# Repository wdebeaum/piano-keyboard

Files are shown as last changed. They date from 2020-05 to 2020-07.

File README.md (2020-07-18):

# Modular Piano Keyboard

By William de Beaumont

[CC BY 4.0](https://creativecommons.org/licenses/by/4.0/)

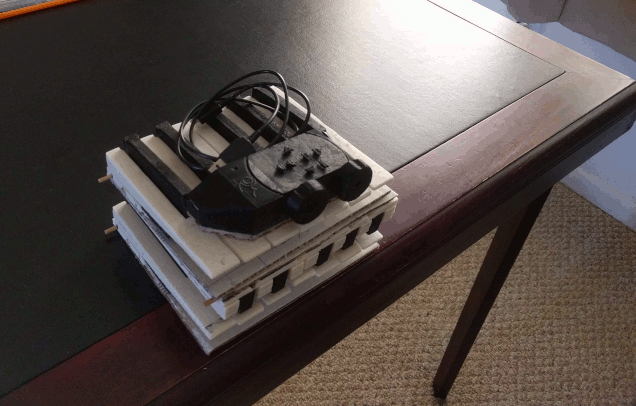
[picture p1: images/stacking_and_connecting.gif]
three octaves and end piece being unstacked and then connected


## Description

A DIY portable electronic piano keyboard with full-size keys, composed of several identical single-octave modules plugged together. Made using 3D printing, through-hole soldering, and easily obtainable parts.

Each key has two switches that close at different heights, in order to detect the velocity with which the key is pressed. Each octave (12 keys) has 3 8-bit shift registers that take input from the 24 switches in parallel, and shift output out serially, down towards the low (left) side of the keyboard.

That side may be connected to an end piece that uses a Teensy 4.0 to drive the shift registers and act as a USB MIDI controller. The end piece also has pitch bend and modulation wheels, a connection for a sustain pedal, and buttons to adjust a few settings.

Alternatively, you can connect that side of the keyboard to your own microcontroller, using an SPI port and one GPIO pin. The included `spi2midi` program will turn keypresses into MIDI commands on `stdout` if it is run on a Raspberry Pi connected to the keyboard as shown in [`wiring.h`](wiring.h).

## Instructions

 - [Bill of Materials](BOM.md)

 - [Building Instructions](BUILD.md) (many pictures)

 - [Usage Instructions](USAGE.md)

## Known issues

 - The key switches sometimes get out of alignment, preventing specific keys from triggering consistently until you take the key off and realign the switch.

 - The connection between the lowest octave and the end piece is a bit wobbly with only one alignment pin.

 - The pitch bend knob has no centering mechanism. I tried to make various kinds of springs for it, but the results were unsatisfying.

 - The hole in the end piece enclosure intended to let the LED on the Teensy shine through is too far away from it to matter. Maybe a light pipe would improve it. But as it is, the light shines out the right side anyway, so whatever.

## Future work

 - Better integration with ALSA MIDI ports on RasPi, ultimately letting it act as a standalone musical instrument by connecting to a soft synth.

 - Surface-mount version of octave PCB for mass production? Switches are still labor-intensive, though.

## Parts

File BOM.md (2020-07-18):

# Modular Piano Keyboard

## Octave Bill of Materials

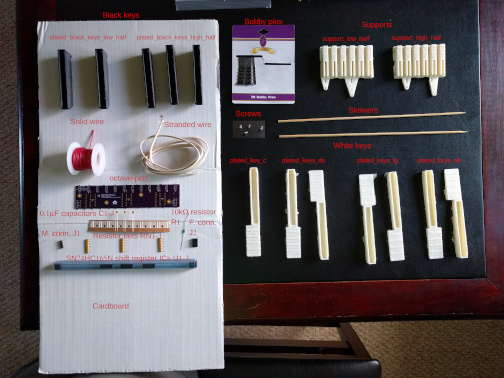
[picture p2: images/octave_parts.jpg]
picture of the parts listed below, laid out on a table


Quantities shown here are for one octave (though you probably want to make at least 3).

### Printed plastic parts

| Ref. | Qty | Description |
|:---- | ---:|:---- |
| `support` | 1 | support for whole octave (or two halves below) |
| `support_low_half` | 1 | support for C-F keys |
| `support_high_half` | 1 | support for F♯-B keys |
| `black_key` | 4 | regular black keys |
| `key_a_sharp` | 1 | A♯ key |
| `key_c` | 1 | C key |
| `key_d` | 1 | D key |
| `key_e` | 1 | E key |
| `key_f` | 1 | F key |
| `key_g` | 1 | G key |
| `key_a` | 1 | A key |
| `key_b` | 1 | B key |

These total about 40cm<sup>3</sup> of black plastic, 60cm<sup>3</sup> of white plastic, and 50cm<sup>3</sup> of additional plastic of any color (the color of the supports doesn't matter).

### Electronic components

| Ref. | Qty | Mfg. part no. | Digikey part no. | Description |
|:---- | ---:|:--- |:--- |:--- |
| U1-3 | 3 | SN74HC165N | 296-8251-5-ND | 8-bit PISO shift register |
| C1-3 | 3 | K104Z15Y5VF5TL2 | BC1160CD-ND | 0.1μF capacitor |
| RN1-3 | 3 | 4609X-101-103LF | 4609X-101-103LF-ND | 8×10kΩ bussed resistor array |
| R1 | 1 | RNF14FTD10K0 | RNF14FTD10K0CT-ND | 10kΩ resistor |
| J1 | 1 | PPTC051LGBN-RC | S5441-ND | 5-pin horiz. 0.1" pitch header, male |
| J2 | 1 | PRPC005SBAN-M71RC | S1111EC-05-ND | 5-pin horiz. 0.1" pitch header, female |

Note that many of these parts are shared between the octaves and the end piece, so you might want to take that into account when computing quantities to order. Even if you don't want to use the Teensy-based end piece, you might want to order 3 more resistors for the whole keyboard, so you can make the level shifter/voltage divider for connecting the 5V output of the keyboard to a 3.3V input on a Raspberry Pi or other microcontroller, as shown in `wiring.h`.

### Other parts and materials

| Qty | Description | How to get |
| ---:|:---|:--- |
| 12 | Bobby pin (metal) | Grocery store, hair care section, pack of 50, UPC 8 50899 00111 0 |
| 4 | M3 machine screw (length ~6mm) | Electronics/hardware store |
| 2 | Bamboo skewer (diameter 3mm, length >= 162.5mm) | Grocery store, barbecue section? pack of... many |
| 1 | Printed circuit board | OSH Park |
| ~30cm | Stranded copper wire | Cut from old telephone cord |
| ~60cm | 22 AWG solid copper wire | I got mine from Adafruit |
| 162.5×138.8mm | Corrugated cardboard | Cut from shipping boxes |
| 141 joints' worth | Solder | been using the same spool forever... |
| ~6 | Cotton swab | Grocery store, probably near the acetone |
| enough to soak the swabs | Acetone | Grocery store, nail care section ("nail polish remover") |
| ~16 drops | Superglue | Grocery store, housewares section |

## End Bill of Materials

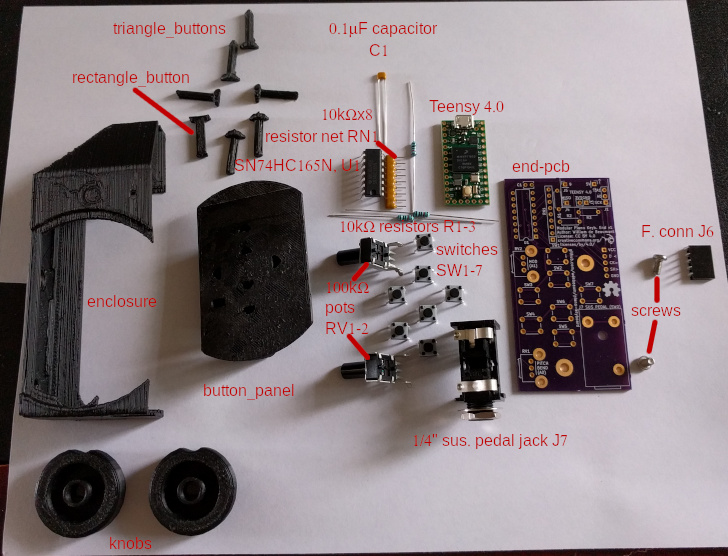
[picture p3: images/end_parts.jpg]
picture of most of the parts listed below, laid out on a table


Parts and quantities for one Teensy-based end piece. (Ignore R1-3 in the photo above, they were used in an earlier version.)

### Printed plastic parts

| Ref. | Qty | Description |
|:---- | ---:|:---- |
| `enclosure` | 1 | main body of enclosure |
| `button_panel` | 1 | part of enclosure around buttons |
| `triangle_button` | 6 | button shafts for directional buttons |
| `rectangle_button` | 1 | button shaft for clear button |
| `knob` | 2 | pitch bend/modulation knobs |

These total about 30cm<sup>3</sup> of plastic.

### Electronic components

| Ref. | Qty | Mfg. part no. | Digikey part no. | Description |
|:---- | ---:|:--- |:--- |:--- |
| J1-5 | 1 | DEV-15583 | 1568-DEV-15583-ND | Teensy 4.0 MCU board |
| U1 | 1 | SN74HC165N | 296-8251-5-ND | 8-bit PISO shift register |
| C1 | 1 | K104Z15Y5VF5TL2 | BC1160CD-ND | 0.1μF capacitor |
| RN1 | 1 | 4609X-101-103LF | 4609X-101-103LF-ND | 8×10kΩ bussed resistor array |
| RV1-2 | 2 | 09VR1M20F1N103B1 | CT3181-ND | 100kΩ potentiometer |
| SW1-7 | 7 | 1825910-6 | 450-1650-ND | SPST tactile pushbutton |
| J6 | 1 | PPTC051LGBN-RC | S5441-ND | 5-pin horiz. 0.1" pitch header, female |
| J7 | 1 | RA49B11 | SC2546-ND | 1/4" mono jack |

### Other parts and materials

| Qty | Description | How to get |
| ---:|:---|:--- |
| 2 | M3 machine screw (length ~6mm) | Electronics/hardware store |
| 1 | Bamboo skewer (diameter 3mm, length >= 30.5mm) | Grocery store, barbecue section? pack of... many |
| 1 | Printed circuit board | OSH Park |
| 42.4×109.3mm | Corrugated cardboard | Cut from shipping boxes |
| 87 joints' worth | Solder | been using the same spool forever... |
| ~5 drops | Superglue | Grocery store, housewares section |

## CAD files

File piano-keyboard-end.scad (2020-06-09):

/* piano-keyboard-end.scad - controls at the left end of piano-keyboard.scad
 * William de Beaumont
 * 2020-06-08
 */

/* TODO:
 - print most of enclosure on its left side
 - print part around buttons and screws separately, upside down
  - extend it all the way down towards the buttons and screw holes
  - make a lip around its edge so it holds down the rest of the top
 - recess the corresponding lip in the rest of the top so the two parts of the top are flush
  - must take care to leave room for sus pedal jack
 - print button extensions horizontally, with triangular cross-section to prevent rotation
  - make user ends of arrow buttons triangular too, pointing out from the center
  - make clear button end rectangular
 - extend holes for sus pedal jack and USB receptacle out towards the right to enable assembly
 - add upside-down shelves along PCB edges
 ? add ribs around inside top corners
 - remove most of bottom side (esp. around screw holes); use glued-on cardboard instead
 ? add skewer hole corresponding to the front one on octave (will it fit under teensy?)
 - taper top and left sides towards back, where teensy is
  - left side taper must be 45° to be printable
 - pitch bend knob torsion spring
  - two slots in knob opposite finger notch, to loop wire through
  - wire wraps around center post at least once
  - wire makes 90° bend to right on other side of knob, so knob can push wire into enclosure
  - two holes in left side of enclosure, near top, to poke other ends of wire through
*/

//
// printer-dependent parameters (see also piano-keyboard.scad)
//

wall_thickness = 1;
gap = 0.3;
thin_wall_deduction = 0.2;
sliding_deduction = 0.3;
epsilon = 0.01;
$fn=24;

//
// locations and sizes of PCB features
//

// reference point is top left corner of PCB; Y is inverted from KiCAD
// x->width, y->height, z->thickness

// the board itself
pcb_width = 1.62*25.4;
pcb_height = 3.23*25.4;
pcb_thickness = 1.6;

// Teensy 4.0
teensy_min_x = 0.87*25.4;
teensy_min_y = -0.35*25.4;
teensy_min_z = 0.1*25.4; // ???
teensy_width = 0.7*25.4;
teensy_height = 1.4*25.4;
teensy_thickness = pcb_thickness; // ???
// guessing based on pictures
teensy_led_x = teensy_min_x + 0.5*25.4;
teensy_led_y = teensy_min_y + 0.13*25.4;
teensy_led_radius = 0.1*25.4/2;

// USB receptacle on Teensy 4.0
// (mostly guesswork from generic USB diagram I googled)
usb_width = 7.5;
usb_height = 2.75+3.35;
usb_thickness = 2.5;
// guessing it's centered on Teensy
usb_min_x = teensy_min_x + (teensy_width - usb_width)/2;
usb_max_y = teensy_min_y + teensy_height + 1.3;
usb_min_z = teensy_min_z + teensy_thickness;

// connector to keys
j5_x = pcb_width;
j5_min_y = -1.62*25.4;
j5_height = 0.5*25.4;
j5_thickness = 0.1*25.4;
j5_min_z = -(pcb_thickness+j5_thickness);

// screws
screw1_x = 1.12*25.4;
screw1_y = -1.35*25.4;
screw2_x = 0.67*25.4;
screw2_y = -2.9*25.4;

// buttons
button_radius = 3.51/2;
button_thickness = 5;
// button centers:
//    x1  x2  x3
// y1     sw1
// y2     sw2
// y3 sw3     sw7
// y4     sw6
// y5 sw4
// y6     sw5
button_x1 = 0.24*25.4;
button_x2 = 0.7*25.4;
button_x3 = 1.15*25.4;
button_y1 = -1.24*25.4;
button_y2 = -1.59*25.4;
button_y3 = -1.84*25.4;
button_y4 = -2.1*25.4;
button_y5 = -2.28*25.4;
button_y6 = -2.47*25.4;

// potentiometers
pot_shaft_radius = 6/2;
pot_shaft_max_x = 0.005*25.4;
pot_shaft_length = 20-8; // quoted as 8mm, but that includes pot body
pot_shaft_min_x = pot_shaft_max_x - pot_shaft_length;
pot_flat_length = 7;
pot_flat_depth = 6-4.5; // how far in from where the circumference would be otherwise
pot1_shaft_y = -1.35*25.4;
pot2_shaft_y = -2.9*25.4;
pot_shaft_z = 0.394*25.4;

// sustain pedal jack
sus_radius = 0.1875*25.4;
sus_x = 1.2730*25.4;
sus_y = -pcb_height;
sus_z = 0.492*25.4;

// max height above pcb of any component (sustain pedal jack)
top_component_thickness = 0.708*25.4;
// ditto for components on bottom (J5)
bottom_component_thickness = 0.1*25.4;

//
// other parameters
//

knob_radius = 15;
knob_width = pot_shaft_length - (wall_thickness+2*(gap+sliding_deduction));
knob_min_x = pot_shaft_min_x;
// use thicker outer wall for knobs so that the gap doesn't show much
knob_wall_thickness = 5;
finger_radius = 5;
finger_depth = 2;

//
// non-printed parts
//

module pcb() {
    translate([0,0,-pcb_thickness/2])
  import("piano-keyboard-end-pcb/piano-keyboard-end-pcb.stl");
  // teensy
    translate([teensy_min_x, teensy_min_y, teensy_min_z])
  cube([teensy_width, teensy_height, teensy_thickness]);
  // usb
    translate([usb_min_x, usb_max_y - usb_height, usb_min_z])
  cube([usb_width, usb_height, usb_thickness]);
}

//
// basic enclosure sketch
//

module enclosure_sketch() {
  difference() {
    electronics_height = pcb_height + teensy_height + teensy_min_y;
    electronics_thickness = top_component_thickness + pcb_thickness + bottom_component_thickness;
    electronics_min_z = -(pcb_thickness + bottom_component_thickness);
    // main body
      translate([-(gap+wall_thickness), -(pcb_height+gap+wall_thickness), electronics_min_z-(gap+wall_thickness)])
    cube([pcb_width+gap+wall_thickness, electronics_height+2*(gap+wall_thickness), electronics_thickness+2*(gap+wall_thickness)]);
    // main hollow
      translate([-gap, -(pcb_height+gap), electronics_min_z-gap])
    cube([pcb_width+gap+epsilon, electronics_height+2*gap, electronics_thickness+2*gap]);
    hole_thickness = wall_thickness+2*epsilon;
    // hole for usb receptacle
      translate([usb_min_x-gap, usb_max_y-hole_thickness+epsilon, usb_min_z-gap])
    cube([usb_width+2*gap, hole_thickness, usb_thickness+2*gap]);
    // hole for led (light pipe?)
      translate([teensy_led_x, teensy_led_y, top_component_thickness+gap-epsilon])
    cylinder(r=teensy_led_radius, h=hole_thickness);
    // hole for sustain pedal jack
      translate([sus_x, sus_y-gap+epsilon, sus_z])
      rotate([90,0,0])
    cylinder(r=sus_radius+gap, h=hole_thickness);
    // holes for pots
      translate([epsilon-gap, pot1_shaft_y, pot_shaft_z])
      rotate([0,-90,0])
    cylinder(r=pot_shaft_radius+gap+sliding_deduction, h=hole_thickness);
      translate([epsilon-gap, pot2_shaft_y, pot_shaft_z])
      rotate([0,-90,0])
    cylinder(r=pot_shaft_radius+gap+sliding_deduction, h=hole_thickness);
    // holes for button stalks
      translate([0, 0, top_component_thickness+gap-epsilon])
    union() {
	translate([button_x2, button_y1, 0])
      cylinder(r=button_radius, h=hole_thickness);
	translate([button_x2, button_y2, 0])
      cylinder(r=button_radius, h=hole_thickness);
	translate([button_x1, button_y3, 0])
      cylinder(r=button_radius, h=hole_thickness);
	translate([button_x3, button_y3, 0])
      cylinder(r=button_radius, h=hole_thickness);
	translate([button_x2, button_y4, 0])
      cylinder(r=button_radius, h=hole_thickness);
	translate([button_x1, button_y5, 0])
      cylinder(r=button_radius, h=hole_thickness);
	translate([button_x2, button_y6, 0])
      cylinder(r=button_radius, h=hole_thickness);
    }
  }
}

//
// mod/pitch pot knob
//

module knob() {
  difference() {
    union() {
      // outer body
      difference() {
	cylinder(r=knob_radius, h=knob_width);
	  translate([0,0,wall_thickness])
	cylinder(r=knob_radius-knob_wall_thickness, h=knob_width-wall_thickness+epsilon);
	// finger notch
	  translate([-(knob_radius+finger_radius-finger_depth), 0, -epsilon])
	cylinder(r=finger_radius, h=knob_width+2*epsilon);
	// TODO anchor for torson spring for pitch bend knob
      }
      // inner post
      cylinder(r=pot_shaft_radius+gap+wall_thickness, h=knob_width);
    }
    // shaft hole
      translate([0,0,-epsilon])
    difference() {
      cylinder(r=pot_shaft_radius+gap, h=knob_width+2*epsilon);
      // flat
	rotate([0,0,-90])
        translate([
	  -(pot_shaft_radius+gap+epsilon),
	  pot_shaft_radius+gap-pot_flat_depth,
	  -2*epsilon
	])
      cube([
        2*(pot_shaft_radius+gap+epsilon),
        2*(pot_shaft_radius+gap+epsilon),
        pot_flat_length - gap + 2*epsilon
      ]);
    }
  }
}

%pcb();
enclosure_sketch();
  translate([pot_shaft_min_x, pot1_shaft_y, pot_shaft_z])
  rotate([0,90,0])
knob();
  translate([pot_shaft_min_x, pot2_shaft_y, pot_shaft_z])
  rotate([0,90,0])
knob();

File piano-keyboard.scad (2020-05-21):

/* piano-keyboard.scad - piano keyboard with dimensions copied from my midi keyboard
 * William de Beaumont
 * 2020-05-21
 */

//
// measurements
//

// measurements taken from my optimus md-1150
octave = 162.5;
white_width = 21.8;
white_gap = octave / 7 - white_width; // suspiciously close to sqrt(2)
black_width = 11; // but slightly narrower at the top
black_top_width = 9.8; // ?
white_depth = 134;
black_min_depth = 77; // at top
black_max_depth = 84; // at bottom, next to top of white key
white_travel = 16.9 - 6.1; // at max end of white key
// measured
//black_travel = 12 - 5.6; // ? at max end of black key (but tilted)
// calculated with the assumption that the travel angle is the same for b&w
black_travel = white_travel * black_max_depth / white_depth;
// height of black key above white key, with neither depressed
black_min_height = 8; // at min end of key, toward fulcrum
black_max_height = 12; // at max end of key
corner_radius = 1.5; // ? approx (maybe less for top of black keys)
// ^^^ doesn't apply to cutouts in white keys for black keys

// measurements from paper transfer
c_stem_width = 13;
d_stem_width = 14;
e_stem_width = 12.75;
f_stem_width = 12.1;
g_stem_width = 12.15;
a_stem_width = 12.15;
b_stem_width = 12.1;

black_gap =
  (octave - 
    ( // add up everything but the black gaps
      c_stem_width +
      d_stem_width +
      e_stem_width +
      f_stem_width +
      g_stem_width +
      a_stem_width +
      b_stem_width +
      5*black_width +
      2*white_gap
    )
  ) / 10;

c_x = 0;
c_sharp_x = c_x + c_stem_width + black_gap;
d_x = c_sharp_x + black_width + black_gap;
d_sharp_x = d_x + d_stem_width + black_gap;
e_x = d_sharp_x + black_width + black_gap;
f_x = e_x + e_stem_width + white_gap;
f_sharp_x = f_x + f_stem_width + black_gap;
g_x = f_sharp_x + black_width + black_gap;
g_sharp_x = g_x + g_stem_width + black_gap;
a_x = g_sharp_x + black_width + black_gap;
a_sharp_x = a_x + a_stem_width + black_gap;
b_x = a_sharp_x + black_width + black_gap;

// echo centers of key stems in inches for PCB layout
echo(
c=(c_x +c_sharp_x )/(2*25.4),
cs=(c_sharp_x +d_x )/(2*25.4),
d=(d_x +d_sharp_x )/(2*25.4),
ds=(d_sharp_x +e_x )/(2*25.4),
e=(e_x +f_x )/(2*25.4),
f=(f_x +f_sharp_x )/(2*25.4),
fs=(f_sharp_x +g_x )/(2*25.4),
g=(g_x +g_sharp_x )/(2*25.4),
gs=(g_sharp_x +a_x )/(2*25.4),
a=(a_x +a_sharp_x )/(2*25.4),
as=(a_sharp_x +b_x )/(2*25.4),
b=(b_x +octave)/(2*25.4)
);

/* bobby pin measurements
	o  ends
	|
	| o
max	|/	min length
length	|\
	|/  m
	|\
	| |
	| |
	 U

	 u
*/
bpin_width = 1.6;
bpin_thickness = 0.7;
bpin_end_thickness = 1.7; // max
bpin_u_radius = 5 / 2; // measured when unaltered: 3.8 / 2;
bpin_max_length = 50;
bpin_min_length = 46;
bpin_u_m = 17.5;
bpin_m_length = bpin_min_length - bpin_u_m;
bpin_m_pitch = 22 / 4;

bpin_angle = 7.4; // after unbending

// skewer measurements

skewer_radius = 3 / 2; // 3mm diameter skewers

// M3 screw measurements

/*   |    | head radius
      _________  ____
     /         \ head height
     |_________| ____
        <   >     ^
	<   >     threads height
	<___>    _V__
       |  | threads radius
*/

screw_threads_radius = 3/2;
screw_threads_height = 6;
screw_head_radius = 5/2;
screw_head_height = 2;

// electronics measurements

pcb_thickness = 1.6;
// this is what the TI datasheet says:
//chip_thickness = 2*2.54; // 2/10 inch
// this is what I measured (includes wide part of pins extending below plastic)
chip_thickness = (5/32) * 25.4; // 5/32 inch
// half of the 7/100 inch I shaved off the left side of the PCB to account for
// forgetting about the fact that the gap between keys is on the right side of
// the keys only when doing the above echo to get key stem centers in inches
pcb_x_fudge = - (7/2) * 0.254;

// mounting hole centers
//             inches
pcb_hole_1_x = 0.30	*25.4;
pcb_hole_1_y =-0.60	*25.4;
pcb_hole_2_x = 1.95	*25.4;
pcb_hole_2_y =-1.05	*25.4;
pcb_hole_3_x = 4.05	*25.4;
pcb_hole_3_y =-0.60	*25.4;
pcb_hole_4_x = 5.75	*25.4;
pcb_hole_4_y =-1.05	*25.4;

pcb_hole_radius = 3.2 / 2;

// 22 AWG wire
wire_radius = 0.644/2;

// end measurements

//
// parameters that depend on printer capabilities
//

// height of a single layer of extrusion
layer_height = 0.4;
// how thick should walls be, in general?
wall_thickness = 1;
// size of gap between parts that are meant to fit together but not slide easily
gap = 0.3;
// additional gap for thin walls that tend to ooze and become thicker than
// designed
thin_wall_deduction = 0.2;
// additional gap for parts that are meant to slide easily past each other
sliding_deduction = 0.3;
// how much small vertical holes shrink (additional radius to compensate)
small_v_hole_shrinkage = 0.25;

// small value used to avoid coinciding surfaces for CSG operations
epsilon = 0.01;

// use many facets for cylinders
$fn=24;

//
// common computed values
//

// gap between keys and their supports
support_gap = gap + thin_wall_deduction + sliding_deduction;

// thickness of top of white keys (relevant at thin end toward player)
white_thickness = 2*corner_radius;

// key hinge dimensions
hinge_radius = 2*wall_thickness;
hinge_height = wall_thickness + 0.5/*for imperfect printing*/;

// dimensions of extra chunk at back of each key, behind hinge
key_back_width = black_width;
key_back_depth = hinge_radius + wall_thickness + support_gap + wall_thickness;
white_back_height = white_travel + white_thickness;
black_back_height = white_back_height + black_min_height;

// dimensions of hollow underside of each key
hollow_width = key_back_width - 2*wall_thickness;
hollow_height = white_travel;

// dimensions of key supports and base
support_base_height = pcb_thickness + chip_thickness;
support_width = hollow_width - 2*support_gap;
support_depth = 50;
support_back_depth = 3*wall_thickness;

skewer_hole_radius = skewer_radius + gap + sliding_deduction;

support_hole_ir = screw_threads_radius + small_v_hole_shrinkage; // NOTE: no gap so threads bite
support_hole_or = support_hole_ir + wall_thickness;

//
// parts
//

// bobby pin (for showing assembly)
module bpin() {
    translate([0,-(bpin_min_length - bpin_u_radius),-bpin_u_radius])
  cube([bpin_width, bpin_min_length - bpin_u_radius, bpin_thickness]);
    rotate([-bpin_angle,0,0])
    translate([0,-(bpin_max_length - bpin_u_radius),bpin_u_radius - bpin_thickness])
  cube([bpin_width, bpin_max_length - bpin_u_radius, bpin_thickness]);
    rotate([0,90,0])
  cylinder(r = bpin_u_radius, h = bpin_width);
}

// hole in support for bobby pin
module bpin_hole() {
  intersection() {
    // NOTE: could have used bpin_max_length instead of support_depth, but would have made disassembly hard
      translate([0, -support_depth, -(bpin_u_radius + support_gap)])
    cube([bpin_width + 2*support_gap, support_depth, black_back_height]);
      rotate([-bpin_angle,0,0])
      translate([-epsilon, -support_depth, bpin_u_radius+support_gap-black_back_height])
    cube([bpin_width + 2*support_gap + 2*epsilon, support_depth, black_back_height]);
  }
    rotate([0,90,0])
  cylinder(r = bpin_u_radius + support_gap, h = bpin_width + 2*support_gap);
}
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

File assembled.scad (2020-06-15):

include <octave.scad>;
include <end.scad>;

module assembled() {
  assembled_octave();
  /* too much for OpenSCAD to handle
    translate([octave,0,0])
  assembled_octave();*/
    translate([-(pcb_width+support_gap),-(support_depth - key_back_depth)+skewer_hole_radius+5*wall_thickness-skewer_y/*-support_gap*/,-support_gap])
  assembled_end();
}

// To view, comment out assembled_end() in end.scad and assembled_octave() in
// octave.scad, then uncomment the following:
//assembled();

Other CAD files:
common.scad
end.scad
logo.scad
octave.scad

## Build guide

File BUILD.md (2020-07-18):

# Modular Piano Keyboard

## Octave Building Instructions

These are the building instructions for a single octave module of the modular piano keyboard. The instructions for the end piece that connects the octaves to a computer appear later in this document.

### Plastic Parts

The keys and their support structure can be printed on a 3D printer. Open `octave.scad` in [OpenSCAD](https://www.openscad.org/). By default this shows one assembled octave, including ghosts for the non-printed parts. You can also see a version with a cutaway in the C key to show how things fit together, by commenting out `assembled_octave();` and uncommenting `cutaway();`, at the end of the file.

You may need to adjust some parameters in the section labeled "parameters that depend on printer capabilities". I use an original [Printrbot](https://reprap.org/wiki/Printrbot), printing in ABS plastic onto blue painter's tape with a coating of ABS glue (made by dissolving waste ABS in a small amount of acetone to make it just gooey enough to spread). The Printrbot has a relatively small print bed (~ 124mm × 144mm, the white keys just barely fit), and printing in ABS onto tape means I have to worry a lot about prints curling up due to differential thermal contraction, especially with long thin pieces like piano keys. I also tend to have problems with close-fitting parts, solved with the `gap` parameter and a few others for specific situations. These issues are why I don't include my STL files here, only the original OpenSCAD file; you really should make your own STLs.

To show printable parts, comment out `assembled_octave();` and uncomment one line at a time from the "recommended printing order" section (make sure to read the comments there for more tips). You can then generate an STL file for each print (`Design` > `Render`, then `File` > `Export` > `Export as STL...`). I use Slic3r to generate gcode from the STL, with 20% fill density, and 2 solid layers on all sides.

Note that you have a couple of options for printing the black keys and the supports. I use the separate low and high halves for both, but if your printer is big enough and you're not worried about curling, you can try printing a whole octave at a time.

White keys are printed two at a time, again for space and curling reasons, but also because fit issues are likely to show up here. You wouldn't want to print a whole octave of white keys only to find out they don't quite fit on the supports and you have to adjust the parameters slightly. If you do in fact want to print a whole octave of white keys, you can try calling `plated_white_keys();` instead. If you are having curling issues, I don't recommend trying to print the white keys one at a time diagonally; I tried that a couple of times and had bad results.

You should be checking that the keys fit on their supports immediately after printing them, so that you can either make adjustments to the parameters, or just shave or sand them down to make them slide freely up and down. See "Attach keys" below. You should also check that the bobby pins fit in each slot before soldering them to the PCB. You might want to assign specific pins to specific slots in order to fine tune how the pins are bent, so that the white keys sit at the same height and require the same force to press.

Be careful when testing the bobby pins in their slots. They can shoot out suddenly, so keep a finger on them to prevent that, if it would stick a pin in your eye.

### Printed Circuit Board (PCB)

The circuit is designed in [KiCAD](https://kicad-pcb.org/). You can open the project file `octave-pcb/piano-keyboard-pcb-v2.pro` in KiCAD and use it to export Gerber files if you need to. I used [OSH Park](https://oshpark.com/)'s 2-layer prototype service, which accepts `.kicad_pcb` files directly. I got 3 copies of this board, unpopulated, for $44.45 delivered (this was by far the most expensive part, except for my own labor).

#### Solder components to the bottom

All the components on the PCB are through-hole soldered. Everything except for the switches (i.e. wires) goes on the bottom. I recommend leaving the switches for last, and doing everything else in order from thinnest to thickest:

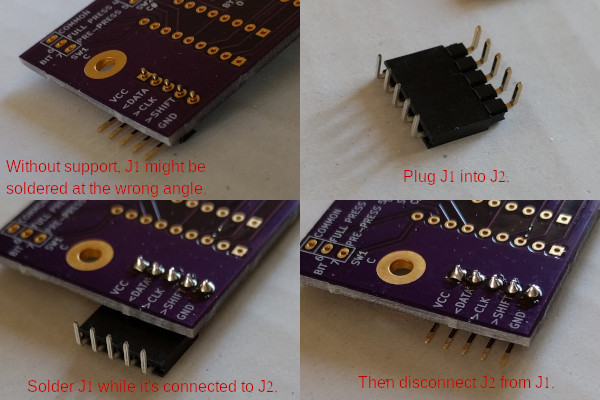
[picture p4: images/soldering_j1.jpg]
how to solder J1
 - Connectors J1-2. Do the male connector J1 first, while it's plugged into the female connector, to make sure there's enough space between the pins and the board.<br>
 - Resistor R1.
 - Chips U1-3. Note that these set the maximum height of the board.
 - Capacitors C1-3. These are about the same height; if not, bend them over a little.
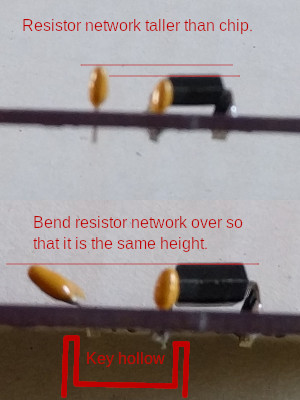
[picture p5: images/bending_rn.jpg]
how to bend RN1-3
 - Resistor networks RN1-3. These are slightly taller than the chips, but you can bend them over slightly before soldering. I recommend bending them away from the adjacent chips, so that the pins poking through the other side go towards the chips, and thus towards the middle of the key they're under. This should make them fit in the hollow in the bottom of the key when it's pressed.<br>

Cut off the excess leads from the resistor and capacitors, and optionally save them for later.

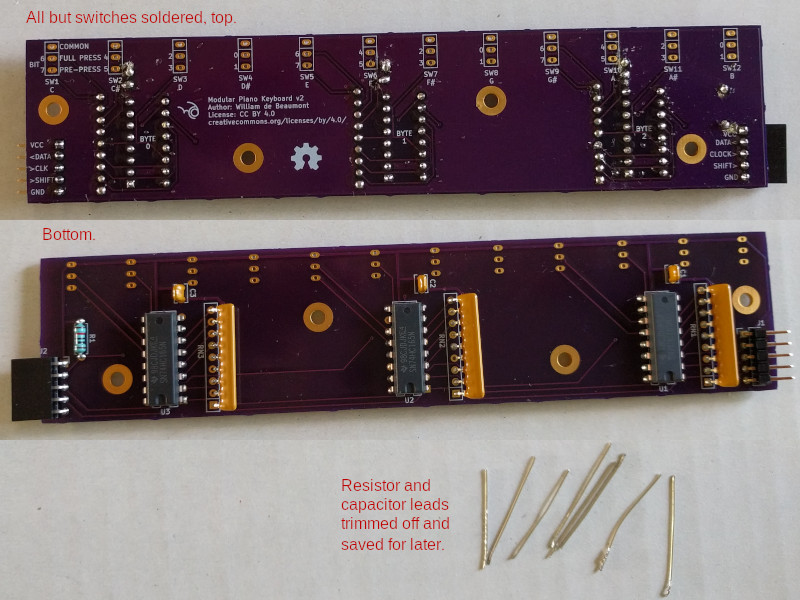
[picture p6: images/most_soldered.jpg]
board with most components soldered and leads trimmed


#### Make switches on the top

Make the switches from the bobby pins and wire, and solder them to the top side of the board (opposite all the other components):

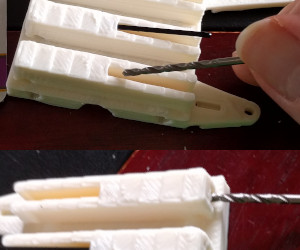
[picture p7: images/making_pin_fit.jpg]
making the pin fit
 - Unbend the bobby pin slightly, so that it fits snugly in the slots in the support, and takes an appropriate amount of force to push down. If it doesn't go in all the way, try reaming out the slot with a drill bit to remove any extra blobs of plastic that may be interfering (especially from the top, where the bridging might have sagged into the slot).<br>
 - Remove any coating from the wavy (bottom) side of the bobby pin where you'll be soldering, and from the inside of the straight (top) side where the other wires will make contact when the switch is closed. You can do this with acetone and a cotton swab. Don't remove the coating from the bulbs on the ends or they'll fall off and leave you with a sharp edge. Also don't inhale the acetone.
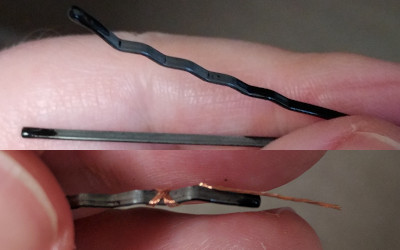
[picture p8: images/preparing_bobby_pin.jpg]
preparing the bobby pin
 - Cut 2-3cm of uninsulated stranded copper wire and wrap one end around the wavy side of the bobby pin, with enough of the end of the wire hanging over the end of the pin so that you can poke it through the hole closest to the edge of the PCB. Solder the wire and the pin together where you wrapped it.<br>
 - Solder that wire into that hole, making sure that the bottom side of the bobby pin ends right about where the PCB begins (no overlap, maybe a 1mm gap). If the wire is too short, the pin won't go all the way into its slot; if it's too long, it will arch up and interfere with the other wires.
 - Strip the ends of a ~2cm piece of solid copper wire, and solder it into the middle hole. You can reuse the leads cut off of the resistor and capacitors for some of these.
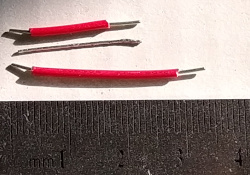
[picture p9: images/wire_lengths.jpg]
wire lengths
 - Similarly use ~3.5cm of solid copper wire with the last hole.<br>
 - Bend the shorter, middle wire straight into the middle of the bobby pin, with the free end bent up a little.
 - Bend the longer wire away from the bobby pin, along the board, and then make a sharp U-shaped bend up and back towards the middle of the bobby pin, not as far as the shorter wire. Again, bend the free end up, a little less than the shorter wire.

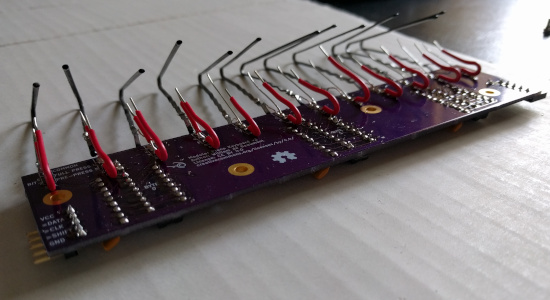
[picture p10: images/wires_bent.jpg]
bent wires


The wire bending doesn't have to be perfect for now; save that for when the PCB is inserted into the plastic support. The goal is for the bobby pin, when pressed down, to make contact with the long wire first, and then the short wire. The U-bend in the long wire makes it so it can spring back instead of being permanently bent down when you first press the key.

Note that the C and G keys have screw holes near where the longer wire is soldered. The U-bend in the longer wires for these keys should just about touch the screw heads. In general the U-bends for all the keys need to be tight in order to avoid having the key push down on the wire there and make it lose contact with the bobby pin.

After you're finished soldering, it's a good idea to check for short circuits with a multimeter. At least check that VCC and ground aren't shorted before plugging it in.

### Final Assembly

At this point, you should be sure that all the keys fit on their supports and slide freely. But leave the keys off for the next step.

#### Insert PCB into support

Line up all the bobby pins in their slots in the support, and start pushing them in. If you printed the support in two halves, you can do this one half at a time to make it easier. Be careful not to break the stranded wires connecting the pins to the PCB. You can use the top of one of the white keys as a tool to push on the top sides of all the pins at once, to make them go in evenly. Be patient. Note that if the switch wires stick out of the bottom side of the board a little, they might catch on the part of the support under the PCB. You can wiggle the PCB up and down a little to get past this, and get the wires that stick out into the depressions for them in the PCB support struts. Push the bobby pins and PCB all the way in, so the back edge of the PCB is up against the front of the main part of the support.

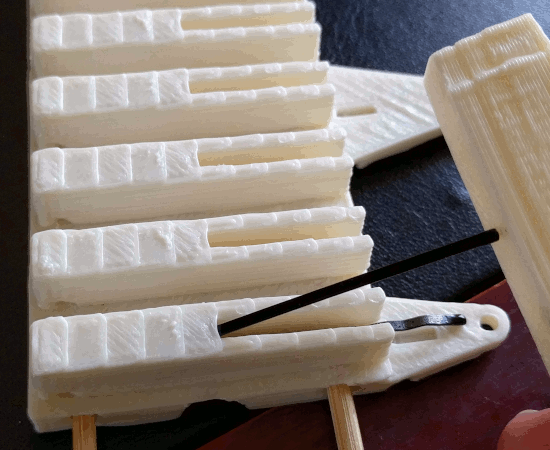
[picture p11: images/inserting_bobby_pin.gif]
inserting one pin

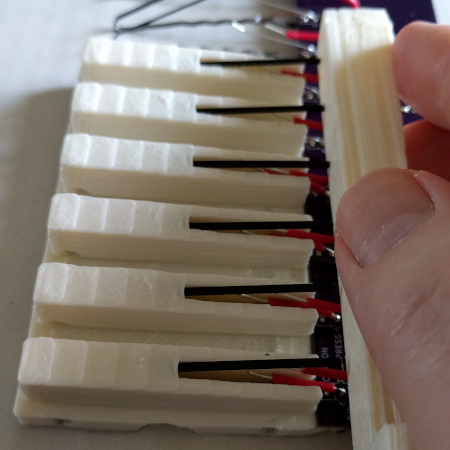
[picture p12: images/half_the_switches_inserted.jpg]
half the switches inserted


You should be able to see the back of the pins through the holes in the backs of the support walls. If you need to undo this step later you can poke another pin through those holes from the back, to loosen the pins.

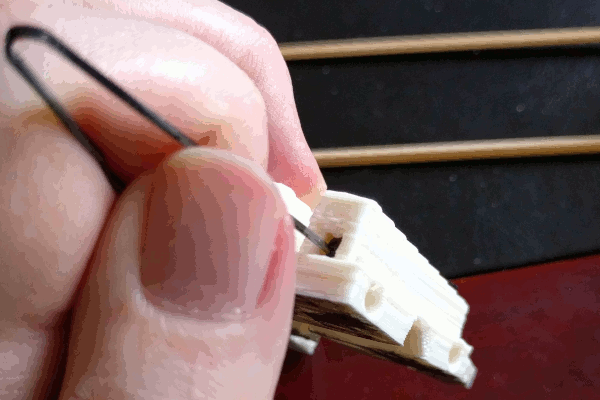
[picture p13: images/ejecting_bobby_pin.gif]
ejecting a pin from the back


#### Secure supports and PCB

Insert the skewers in the two horizontal holes in the bottom of the support (now is a good time, especially if you printed the support in two halves). You should cut them to the same length as the octave, 162.5mm. Insert them so that the back skewer hangs out of the left side by 1cm, and the front skewer hangs out of the right side by 1cm. If they're loose, you can glue them in place later. If they're too tight to insert, check for plastic blobs inside the holes getting in the way and remove them with a knife and/or a drill. If there's nothing in the way, try flexing the support to straighten the holes as you insert the skewers.

Insert the four screws through the PCB and into the corresponding holes in the support. You might need to use some force when screwing them in for the first time, in order to cut the threads into the plastic. Do this on a surface you don't care about the finish of, just in case the screws poke out a little from the bottom of the support.

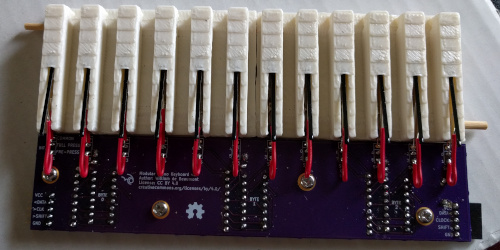
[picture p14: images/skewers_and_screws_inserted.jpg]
skewers and screws inserted


#### Check switches

Make sure the switch wires are bent properly (see PCB instructions above), since inserting the PCB into the support might have knocked them out of alignment. Look into the bobby pin slot from the front and press down on the top of the pin with your finger, so you can see if and when the wires make contact with the pin. You might also want to connect the electronics at this point so you can see when connections are being made that way. It will take some testing and iteration to get this right for each key. You can use an extra bobby pin or two as tools to help you adjust the positions of the wires while they are inside the support.

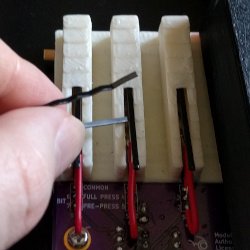
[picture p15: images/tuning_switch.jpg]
adjusting the switch wires for C♯ key with another bobby pin


#### Attach keys

Slide each key onto its support wall, and then slide it forward until the hinge snaps into place. Attach the white keys first and then the black keys. The white keys are C through B, left to right. The black keys are all the same except for the rightmost one, A♯, which has a notch on the bottom right side to accommodate one of the screw heads.

If you printed the support in two halves, check that the F key doesn't noisily rub against the F♯ and G keys. If it does, try to wiggle the support halves around until it doesn't. Failing that, shave down the keys where they rub.

#### Attach cardboard

Cut a rectangular piece of corrugated cardboard, 162.5mm × 138.8mm (these measurements are `echo`'d by OpenSCAD when you show the default `assembled_octave();` scene). Cut it so that the corrugations run parallel to the keys (along the Y dimension). This cardboard helps the keyboard not to tip forward when you play chords, so you don't want it to fold up along the X dimension.

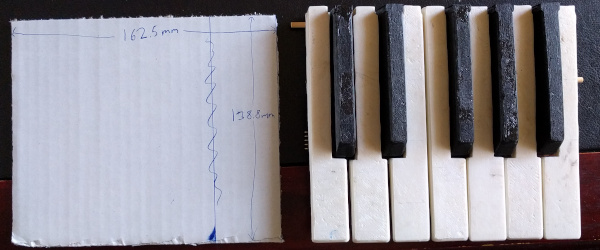
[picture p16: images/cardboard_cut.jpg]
cardboard cut to size


Turn the keyboard upside down and put a small amount of glue on each of the bottom surfaces (and on the skewers if they're still loose). Press the cardboard onto the glued surfaces, taking care to align the back corners of the support with the back corners of the cardboard. Turn the keyboard right side up again and let the glue set.

## End Building Instructions

These are the building instructions for the end piece that connects the chain of octaves to a computer as a USB MIDI device.

### Plastic Parts

The plastic parts of the end can be printed from `end.scad`. You will need the enclosure (`plated_enclosure()`), the button panel (`plated_button_panel()`), two knobs (`knob()`), six triangular buttons, and one rectangular button (`buttons_plated()`). I recommend printing the enclosure and button panel in white, and the knobs and buttons in black, for contrast. You can use the `white_plated()` and `black_plated()` modules to make this easy. But the colors aren't super important here; I was running out of white, so I used black plastic for everything.

You can also view the `assembled_end()` module to see how the end should look when assembled, or animate the `exploded_end()` module to see how to put it together.

You might need to drill out the screw holes in the conical posts on the bottom of the button panel in order to get the screws to fit, since the 3D printer might have dragged the plastic around, or oozed too much plastic, making the holes smaller. The design tries to account for this, but it's not an exact science.

### Firmware

Open `teensy-usb-midi/teensy-usb-midi.ino` in the Arduino IDE software with [Teensyduino](https://www.pjrc.com/teensy/td_download.html) installed. Make sure that in the `Tools` menu, the `Board` is set to `Teensy 4.0`, and `USB Type` is set to `MIDI`. Click the checkmark button in the top left to verify the sketch. This will compile the program and pop up the `Teensy` window. Then push the button on the Teensy with it connected to the computer, which will cause it to download the newly compiled program. (It's easier to reach the button now, before assembly.)

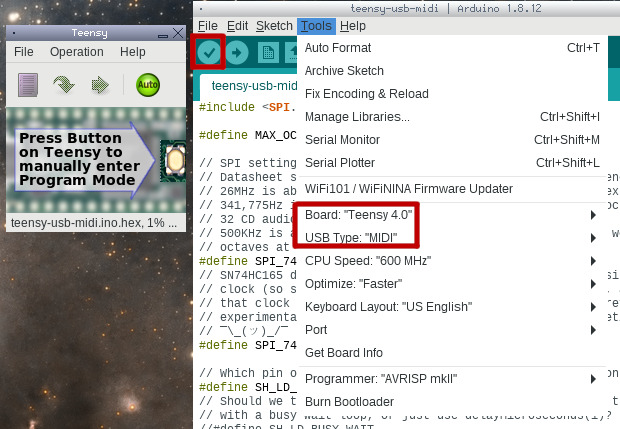
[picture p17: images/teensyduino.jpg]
teensyduino settings, compilation, and flashing


### Printed Circuit Board (PCB)

Again, this is designed in KiCAD (open `end-pcb/piano-keyboard-end-pcb.pro`) and ordered from OSH Park (this time for $26.20 for 3 boards, though I only needed one).

All components except for the 5-pin female connector (J6) belong on the top side of the PCB; J6 goes on the bottom, matching the octaves.

#### Solder shorter components to the top

Solder the resistor network RN1, the capacitor C1, and the chip U1 to the top of the board. Trim the leads from the capacitor, and save them so you can use them for the next step. (Ignore the individual resistors in the photos, they were only used in an earlier version.)

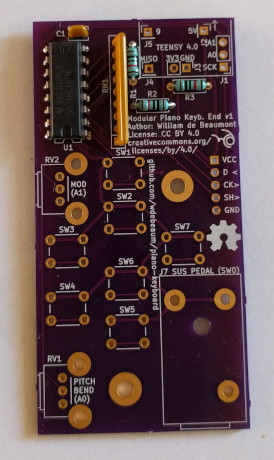
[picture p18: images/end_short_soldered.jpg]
shorter components soldered


#### Solder leads between Teensy and end PCB

Solder the saved leads and/or other solid wire to only the holes in the Teensy that have corresponding holes in the end PCB, in the area in the top right corner labeled `TEENSY 4.0`. All the leads should extend down from the bottom of the Teensy. (Ignore the red wire in the photos, it was only used in an earlier version.)

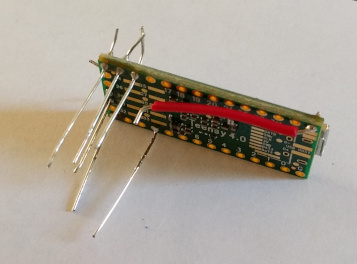
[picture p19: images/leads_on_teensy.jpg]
leads on Teensy


Insert the leads you just soldered to the Teensy into the corresponding holes in the end PCB. Then slide the two boards into the right side of the enclosure (see Final Assembly below) to get the spacing between the boards right. Solder two or three of the leads that are farther away from the plastic so you don't melt it. Then take the boards back out of the enclosure and finish soldering the rest of the leads.

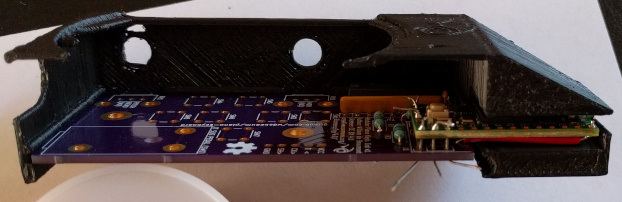
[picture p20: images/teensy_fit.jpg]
teensy fit in enclosure, on pcb


#### Solder taller components to the top

The rest of the top-side components will clip into place. Because of that, they don't need to be supported from below, so you can insert them all now and solder them in one pass: switches SW1-7, potentiometers RV1-2, and the sustain pedal jack J7. The potentiometers might be a little loose; if so, solder them in place before inserting J7, and be careful about keeping them angled correctly. However, if they end up a little off-kilter, you can shave the holes their shafts are supposed to go through in the enclosure until they fit and turn freely.

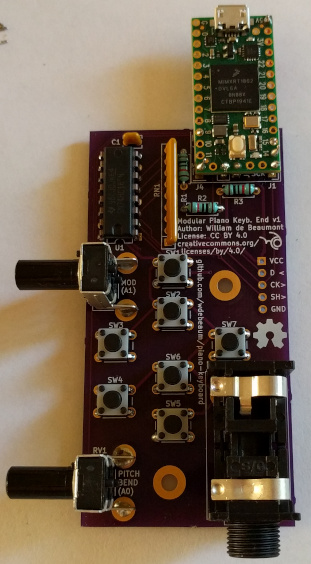
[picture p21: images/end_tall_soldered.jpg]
taller components soldered


#### Solder J6 to the bottom

Finally, solder the 5-pin female connector J6 to the bottom of the end PCB. The leads of the other components sticking out of the bottom will help support the PCB so that J6 is straight.

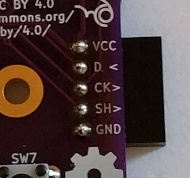
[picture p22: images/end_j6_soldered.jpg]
J6 soldered


### Final Assembly

Viewing the animated version of `exploded_end();` might be helpful here.

#### Insert PCB

Slide the end PCB into the enclosure from the right side, so that the edges go into their slots around the three other sides, the potentiometer shafts go through their holes on the left side, and the sustain pedal jack and the Teensy's USB port slide into their slots on the bottom and the top, respectively. You can thread the nut that came with the sustain pedal jack onto it from the outside, to secure it further.

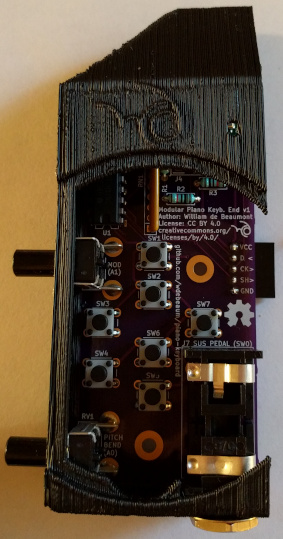
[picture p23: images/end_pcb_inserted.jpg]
end PCB inserted


#### Insert button panel and screws

Put the button panel into its hole in the top of the enclosure, so that the conical screw hole posts line up with the screw holes in the PCB, and screw in the two M3 screws from the bottom.

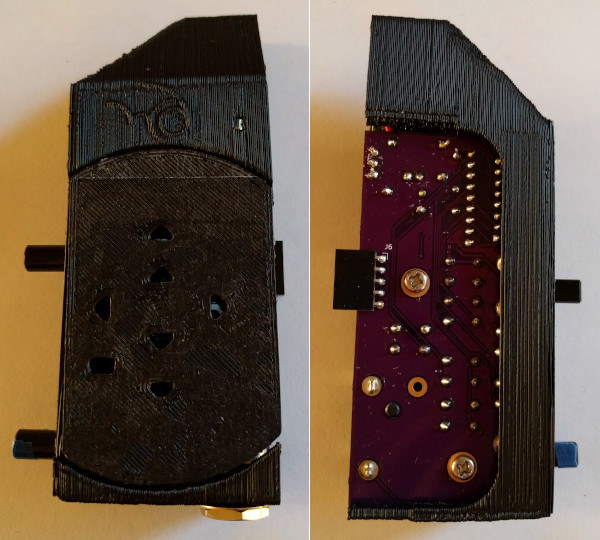
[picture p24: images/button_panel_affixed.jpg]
button panel affixed


#### Insert button shafts and add knobs

Put the button shafts into the button panel. They should feel tight most of the way, and then pop into place. After that, you should be able to feel the click of the switches on the PCB when you push the buttons.

Put the knobs onto the potentiometer shafts. If they're too loose to stay on, wrap a tiny bit of tape around the shafts to make the fit tighter.

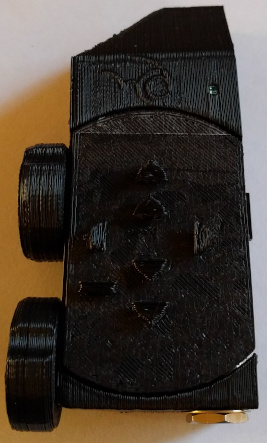
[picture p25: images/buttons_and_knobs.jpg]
buttons and knobs affixed


#### Test

This is a good time to test that everything works properly, since the gluing steps may make disassembly more difficult (in particular, the cardboard covers the screws and makes them inaccessible). See [USAGE](USAGE.md).

#### Glue skewer alignment pin

Cut and glue a 30.6mm piece of skewer into the groove just under the PCB where it connects to the Teensy. This should stick out of the right side by about 1cm, and it will go into the front skewer hole on the first octave when the keyboard is assembled.

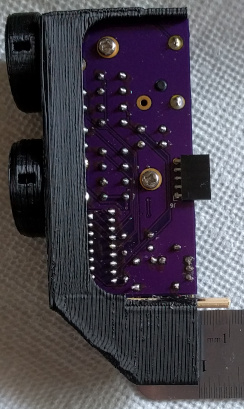
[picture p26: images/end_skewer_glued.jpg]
skewer glued


#### Glue cardboard base

Cut a 42.4×109.3mm piece of the same corrugated cardboard that you used for the bottoms of the octaves, with a 45° bevel cut off of the top left corner, 22.1mm in from the top and left edges. (These dimensions are `echo`'d by OpenSCAD when you show the default `assembled_end();` scene.) Glue it to the bottom of the end enclosure.

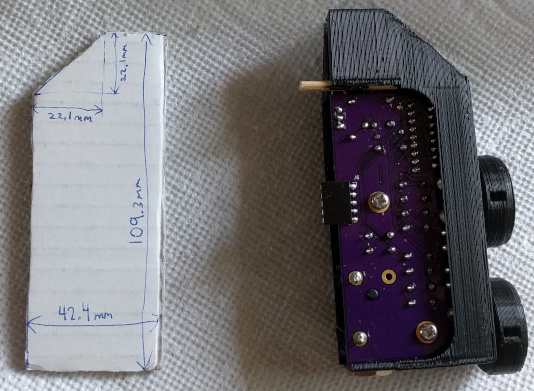
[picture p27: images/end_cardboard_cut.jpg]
cardboard cut


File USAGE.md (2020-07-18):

# Modular Piano Keyboard

## Usage Instructions

Build up to 10 octaves by repeating the [octave building instructions](BUILD.md). Connect them side to side on a flat surface, first lining up the skewers with their holes on the opposide side, and then pushing the octaves together so that the five-pin male connector on the right octave goes into the five-socket female connector on the left octave.

You have a number of options for connecting the octaves to something that will actually play notes:

### With a Teensy 4.0

Build the end piece using the [end building instructions](BUILD.md) (scroll down). Connect the left (five-pin male) connector on the lowest (leftmost) octave to the (five-pin female) connector on the right side of the end piece. Then connect the micro-USB connector on the back of the end piece to a computer or other device that understands USB MIDI devices. Optionally, connect a pedal switch to the 1/4" sustain pedal jack on the front of the end piece.

The front knob is a pitch bend knob. The back knob is for modulation. Not all MIDI synthesizers or instruments support these functions. When you first plug in the USB, the knobs are disabled; in order to enable them, you should calibrate them by moving them all the way in one direction, and then all the way in the other direction. For the best calibration you should have them in the center position (finger notch straight up) when the USB is connected.

The buttons allow you to adjust a few settings. The left and right buttons select which setting is being changed. The inner up and down buttons adjust the currently selected setting in fine increments, and the outer ones adjust it in coarse increments. The rectangular button in the bottom left resets the currently selected setting to the minimum possible value. There are currently 3 different settings you can change:

 1. Transposition. Fine adjustment is by semitone, coarse adjustment is by octave. On startup the lowest pitch on the keyboard is C5.
 2. Instrument (MIDI program). Fine adjustment is by instrument, coarse adjustment is by family (group of 8 instruments in the General MIDI instrument list). On startup this is the first instrument, Acoustic Grand Piano.
 3. MIDI channel. Fine adjustment moves by 1 channel at a time, coarse adjustment moves by 4 channels at a time. On startup this is the first channel.

When you push one of the buttons, the last note you played (or the lowest key if you haven't played any yet) is played again, with any changes applied: it is transposed, or on the new instrument, or on the new channel. This lets you know what you just did.

### With a Raspberry Pi

Connect the left connector on the lowest (leftmost) octave to a Raspberry Pi's 5V power (or 3.3V), SPI port, and one GPIO pin, as shown in the comments in `wiring.h`. If you connect to different pins, change the `#define`s in this file.

Copy this repo to the Pi, and run `make` there to compile the `spi2midi` program. If you run that program, it will write MIDI events to `stdout` for each keypress and release. It will also write debugging information to `stderr`, so it might be useful to do this to just see the debugging information while tuning the key switches:

    ./spi2midi >/dev/null

If, like me, you have a synthesizer connected to a MIDI port on your Linux computer, and you're accessing your Pi over ssh, you can route the MIDI events from the keyboard to the synthesizer with a command like this on your computer:

    ssh pi@pi path/to/spi2midi >/dev/snd/midiC0D0

### With another microcontroller

Connect the left connector on the lowest (leftmost) octave to a microcontroller with a 3.3V or 5V power source, an SPI port, and a GPIO pin. Back to front, the pins are:

 1. Vcc
 2. SPI MISO
 3. SPI clock (~350KHz-21MHz)
 4. Shift/load (connect to GPIO output pin; low loads switch state into the shift registers, high shifts state out of the registers)
 5. Ground

If you use a 5V power source, note that while the circuit will almost tolerate 3.3V inputs on pins 3 and 4 (most keys will work, but with 3 octaves the highest 3 keys won't work consistently), it will still output 5V on pin 2. If your microcontroller can't tolerate 5V on its SPI MISO pin, you should make a voltage divider to change it to something close to what it will tolerate. An easy way to do that is to arrange 3 extra 10kΩ resistors (the same kind you used for R1) like this:

                     SPI MISO on μcontroller (3.3V)
                                ^
                                |
    ground>---/\/\/\---/\/\/\---*---/\/\/\---<pin 2 of keyboard (5V)
               10kΩ     10kΩ         10kΩ

If you use 3.3V power and levels throughout, the voltage divider is unnecessary. And all the keys will work.

Your code should momentarily (min. 14-80ns depending on Vcc) drive pin 4 low, and then keep it high while reading from the SPI port. The first bit you receive will be the pre-press bit for the lowest key (nearest the controller) followed by the full press bit for the same key, followed by the same pattern for each higher key. The bits are labeled in a big-endian fashion within each byte on the PCB; full press bits are even, pre-press bits are odd.

You should read an octave at a time, and stop when you see an octave with all bits set (`0xffffff`); that's the pull-up resistor R1 in the highest octave, terminating the data line.

You should do a complete scan of the keyboard on the order of 1000 times a second. Note the time when the pre-press bit of a given key goes high, and then when you see the full press bit also go high (for two scans, to debounce), compute the time between the two transitions and use that as the velocity of the keypress. When you later see the full press bit go back to low, emit a key release.

Read `spi2midi.c` or `teensy-usb-midi/teensy-usb-midi.ino` for examples of how to do all this.

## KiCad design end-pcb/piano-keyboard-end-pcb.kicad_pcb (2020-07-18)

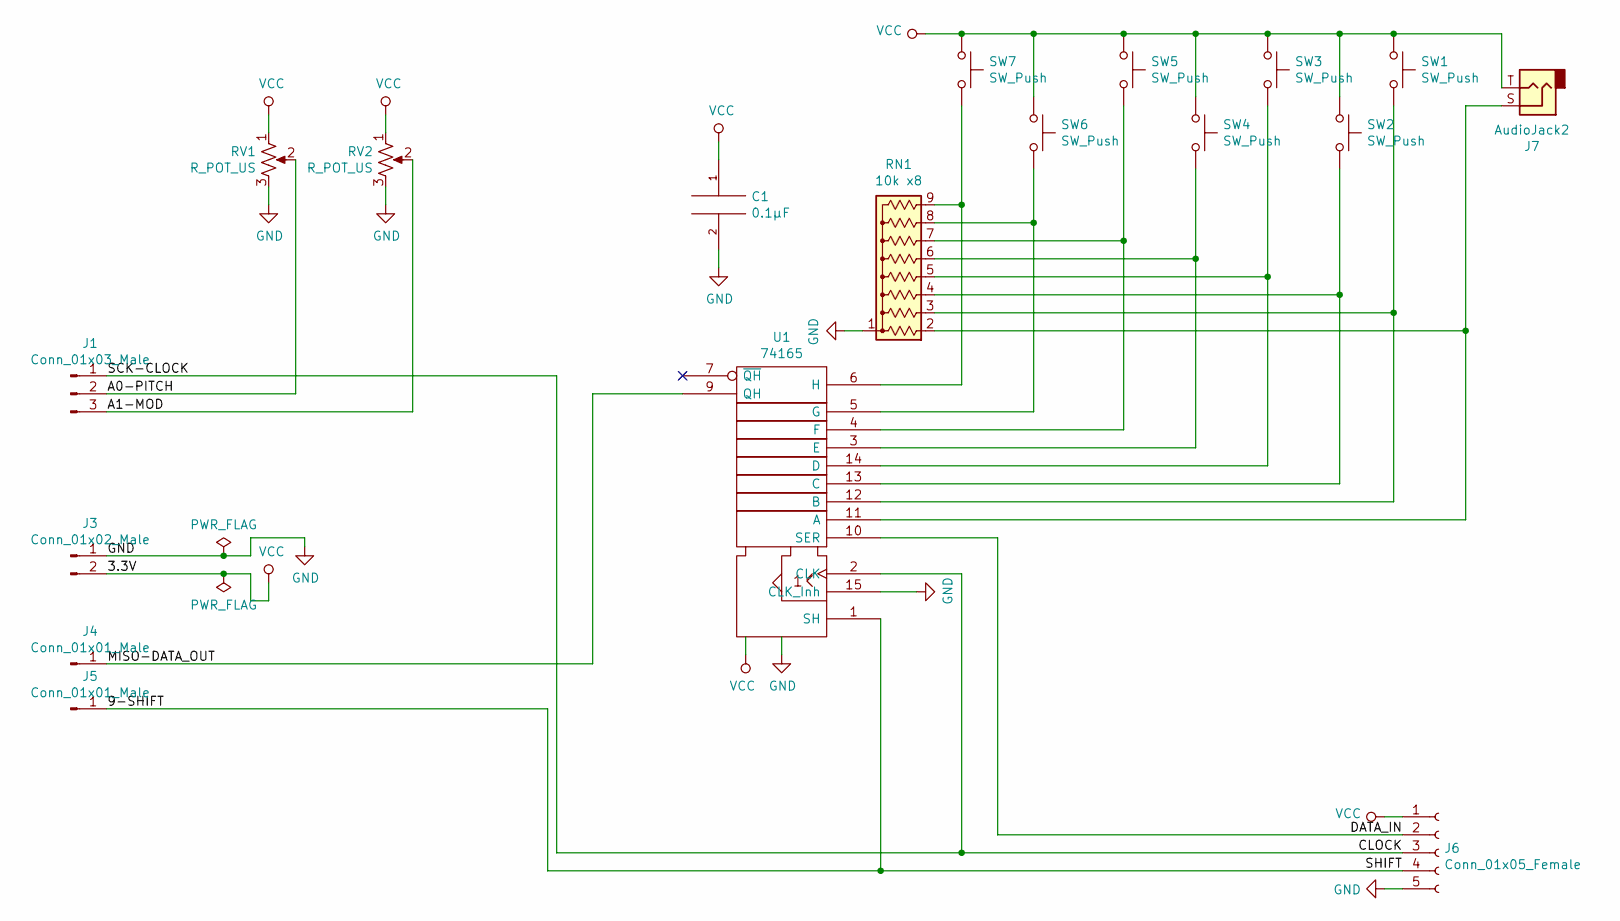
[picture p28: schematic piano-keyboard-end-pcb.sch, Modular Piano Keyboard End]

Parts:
C1: 0.1μF; C_Disc_D3.8mm_W2.6mm_P2.50mm
J1: Conn_01x03_Male; PinHeader_1x03_P2.54mm_Vertical
J3: Conn_01x02_Male; PinHeader_1x02_P2.54mm_Vertical
J4, J5: Conn_01x01_Male; PinHeader_1x01_P2.54mm_Vertical
J6: Conn_01x05_Female; PinSocket_1x05_P2.54mm_Horizontal
J7: AudioJack2; Switchcraft_RA49B11
RN1: 10k x8; R_Array_SIP9
RV1, RV2: R_POT_US; Potentiometer_Bourns_PTV09A-2_Single_Horizontal
SW1, SW2, SW3, SW4, SW5, SW6, SW7: SW_Push; SW_PUSH_6mm
U1: 74165; DIP-16_W7.62mm

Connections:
/9-SHIFT: J5.1, J6.4, U1.1 (SH)
/A0-PITCH: J1.2, RV1.2
/A1-MOD: J1.3, RV2.2
/CLOCK: J1.1, J6.3, U1.2 (CLK)
/DATA_IN: J6.2, U1.10 (SER)
/MISO-DATA_OUT: J4.1, U1.9 (QH)
GND: C1.2, J3.1, J6.5, RN1.1 (common), RV1.3, RV2.3, U1.8 (GND), U1.15 (CLK_Inh)
unnamed: J7.S, RN1.2 (R1), U1.11 (A)
unnamed: RN1.3 (R2), SW1.2, U1.12 (B)
unnamed: RN1.4 (R3), SW2.2, U1.13 (C)
unnamed: RN1.5 (R4), SW3.2, U1.14 (D)
unnamed: RN1.6 (R5), SW4.2, U1.3 (E)
unnamed: RN1.7 (R6), SW5.2, U1.4 (F)
unnamed: RN1.8 (R7), SW6.2, U1.5 (G)
unnamed: RN1.9 (R8), SW7.2, U1.6 (H)
VCC: C1.1, J3.2, J6.1, J7.T, RV1.1, RV2.1, SW1.1, SW2.1, SW3.1, SW4.1, SW5.1, SW6.1, SW7.1, U1.16 (VCC)

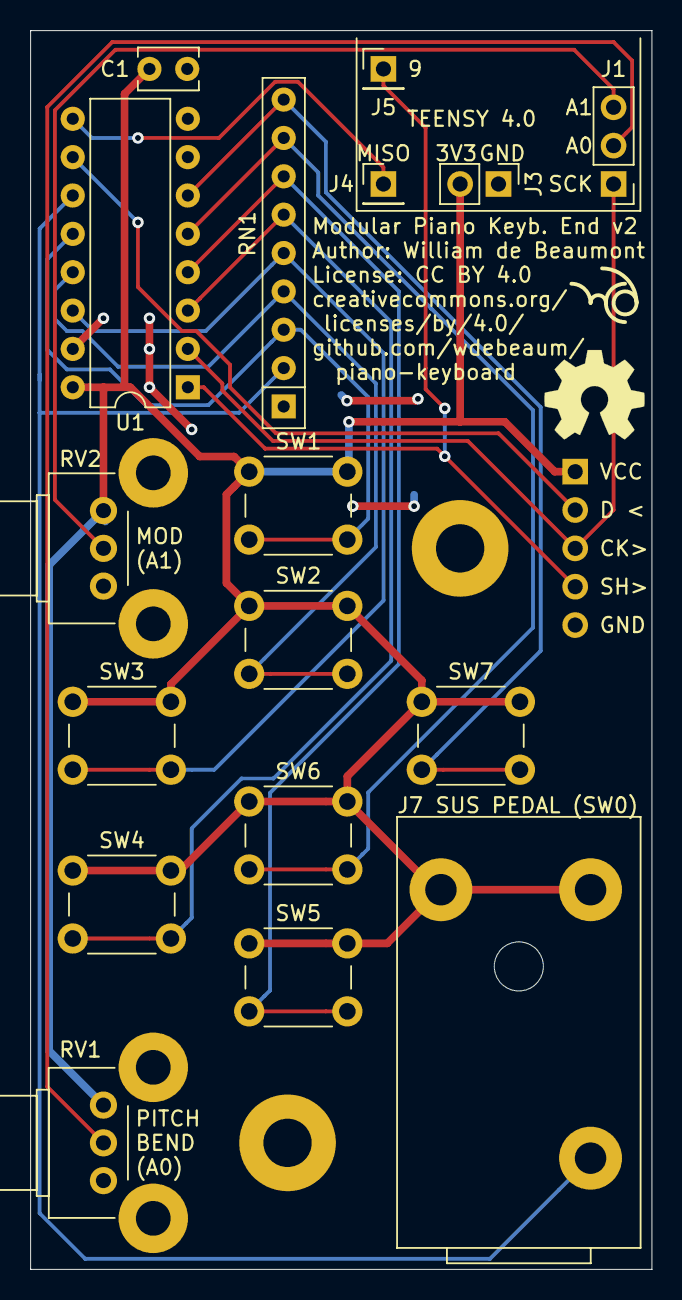
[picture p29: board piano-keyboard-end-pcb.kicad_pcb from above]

Board: 2 copper layers, 41.1 x 82.0 mm, 18 parts (1 on the bottom side), 16 nets.

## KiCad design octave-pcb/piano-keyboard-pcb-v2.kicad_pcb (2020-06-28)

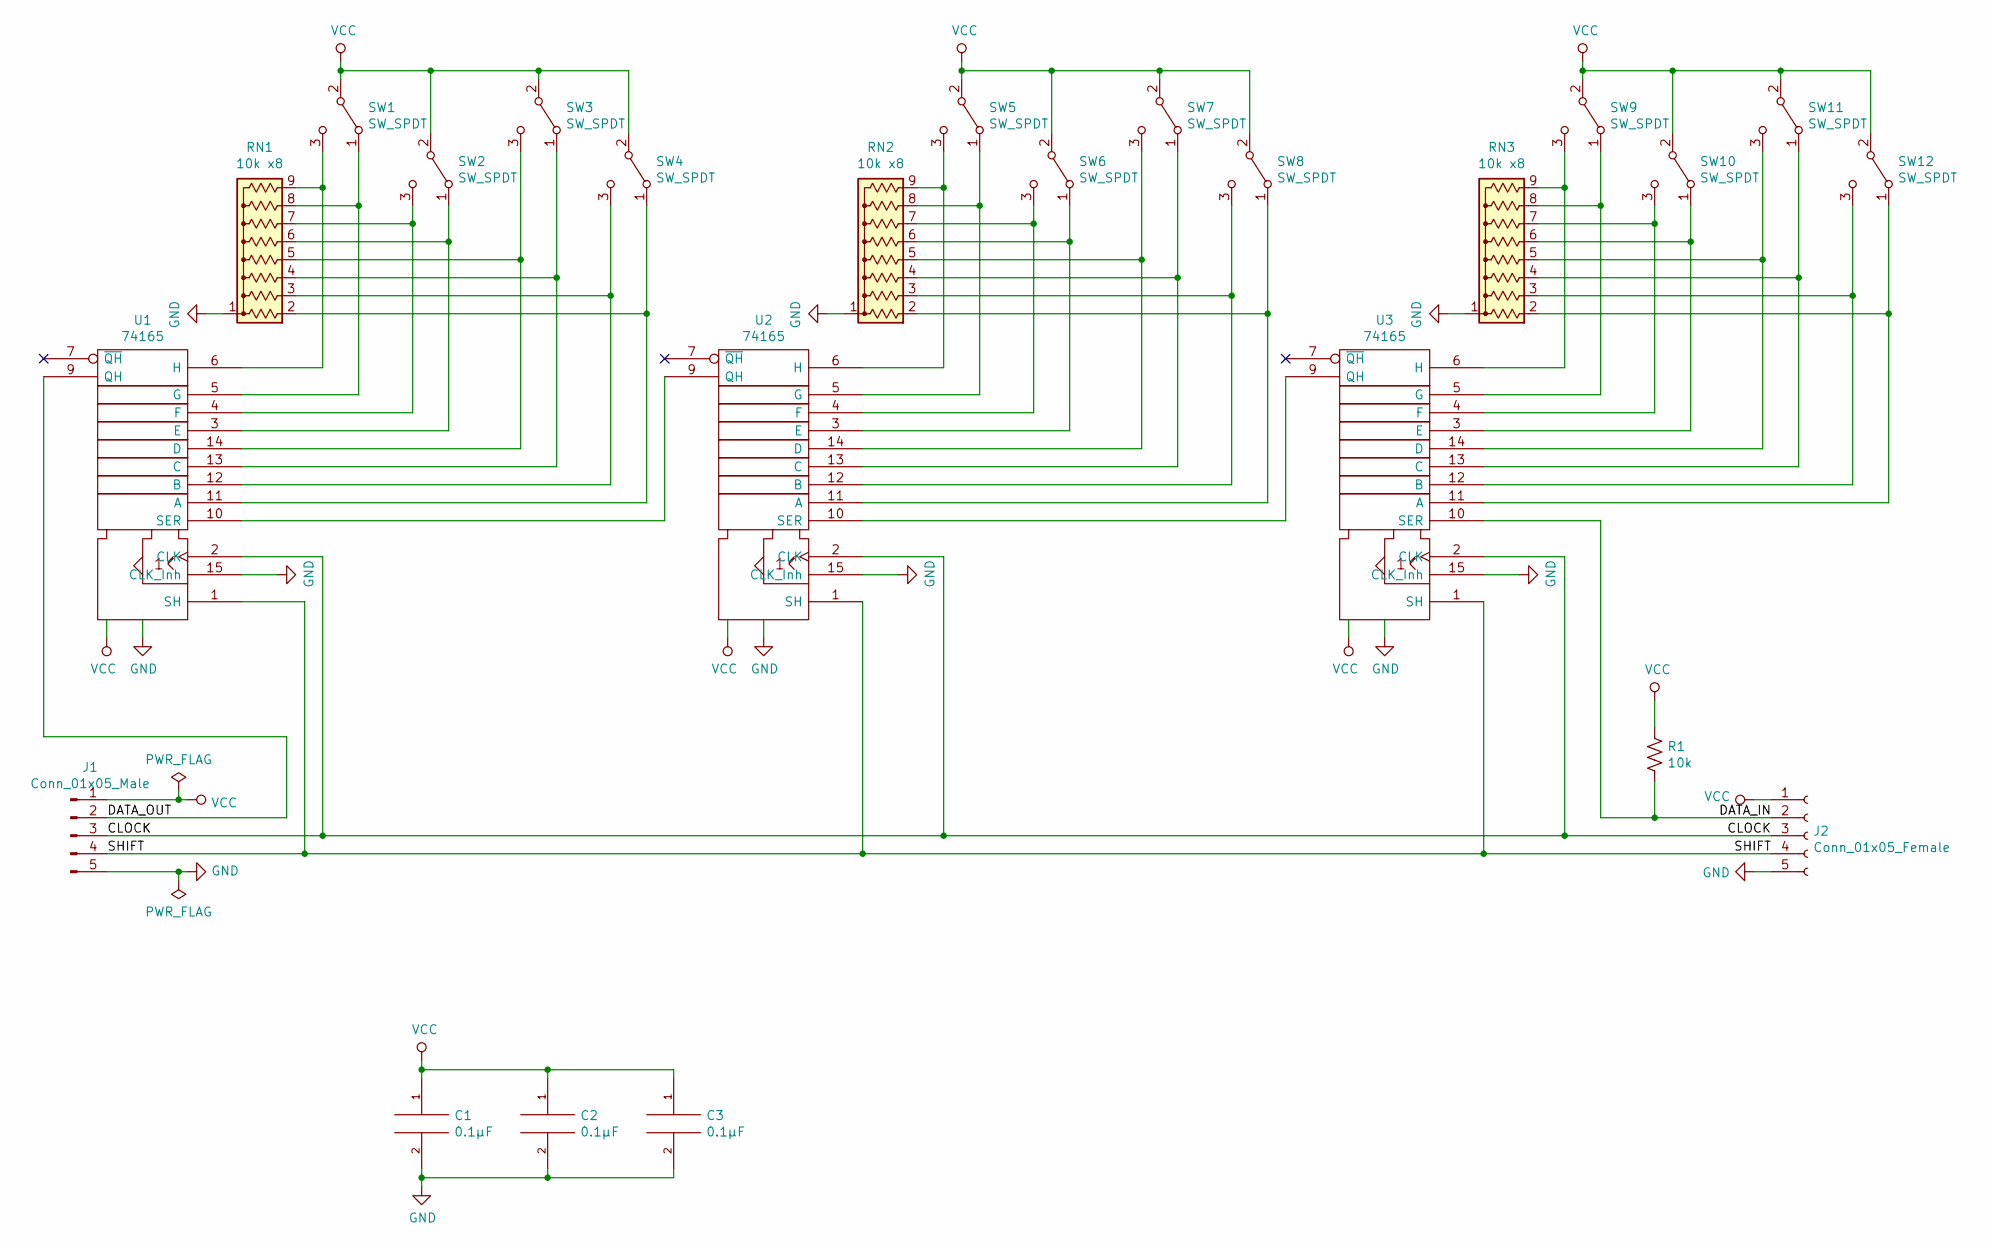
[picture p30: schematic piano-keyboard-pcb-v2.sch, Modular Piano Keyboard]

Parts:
C1, C2, C3: 0.1μF; C_Disc_D3.8mm_W2.6mm_P2.50mm
J1: Conn_01x05_Male; PinHeader_1x05_P2.54mm_Horizontal
J2: Conn_01x05_Female; PinSocket_1x05_P2.54mm_Horizontal
R1: 10k; R_Axial_DIN0207_L6.3mm_D2.5mm_P7.62mm_Horizontal
RN1, RN2, RN3: 10k x8; R_Array_SIP9
SW1, SW2, SW3, SW4, SW5, SW6, SW7, SW8, SW9, SW10, SW11, SW12: SW_SPDT; keysw213
U1, U2, U3: 74165; DIP-16_W7.62mm

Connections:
/CLOCK: J1.3, J2.3, U1.2 (CLK), U2.2 (CLK), U3.2 (CLK)
/DATA_IN: J2.2, R1.2, U3.10 (SER)
/DATA_OUT: J1.2, U1.9 (QH)
/SHIFT: J1.4, J2.4, U1.1 (SH), U2.1 (SH), U3.1 (SH)
GND: C1.2, C2.2, C3.2, J1.5, J2.5, RN1.1 (common), RN2.1 (common), RN3.1 (common), U1.8 (GND), U1.15 (CLK_Inh), U2.8 (GND), U2.15 (CLK_Inh), U3.8 (GND), U3.15 (CLK_Inh)
unnamed: RN1.2 (R1), SW4.1 (A), U1.11 (A)
unnamed: RN1.3 (R2), SW4.3 (C), U1.12 (B)
unnamed: RN1.4 (R3), SW3.1 (A), U1.13 (C)
unnamed: RN1.5 (R4), SW3.3 (C), U1.14 (D)
unnamed: RN1.6 (R5), SW2.1 (A), U1.3 (E)
unnamed: RN1.7 (R6), SW2.3 (C), U1.4 (F)
unnamed: RN1.8 (R7), SW1.1 (A), U1.5 (G)
unnamed: RN1.9 (R8), SW1.3 (C), U1.6 (H)
unnamed: RN2.2 (R1), SW8.1 (A), U2.11 (A)
unnamed: RN2.3 (R2), SW8.3 (C), U2.12 (B)
unnamed: RN2.4 (R3), SW7.1 (A), U2.13 (C)
unnamed: RN2.5 (R4), SW7.3 (C), U2.14 (D)
unnamed: RN2.6 (R5), SW6.1 (A), U2.3 (E)
unnamed: RN2.7 (R6), SW6.3 (C), U2.4 (F)
unnamed: RN2.8 (R7), SW5.1 (A), U2.5 (G)
unnamed: RN2.9 (R8), SW5.3 (C), U2.6 (H)
unnamed: RN3.2 (R1), SW12.1 (A), U3.11 (A)
unnamed: RN3.3 (R2), SW12.3 (C), U3.12 (B)
unnamed: RN3.4 (R3), SW11.1 (A), U3.13 (C)
unnamed: RN3.5 (R4), SW11.3 (C), U3.14 (D)
unnamed: RN3.6 (R5), SW10.1 (A), U3.3 (E)
unnamed: RN3.7 (R6), SW10.3 (C), U3.4 (F)
unnamed: RN3.8 (R7), SW9.1 (A), U3.5 (G)
unnamed: RN3.9 (R8), SW9.3 (C), U3.6 (H)
unnamed: U1.10 (SER), U2.9 (QH)
unnamed: U2.10 (SER), U3.9 (QH)
VCC: C1.1, C2.1, C3.1, J1.1, J2.1, R1.1, SW1.2 (B), SW2.2 (B), SW3.2 (B), SW4.2 (B), SW5.2 (B), SW6.2 (B), SW7.2 (B), SW8.2 (B), SW9.2 (B), SW10.2 (B), SW11.2 (B), SW12.2 (B), U1.16 (VCC), U2.16 (VCC), U3.16 (VCC)

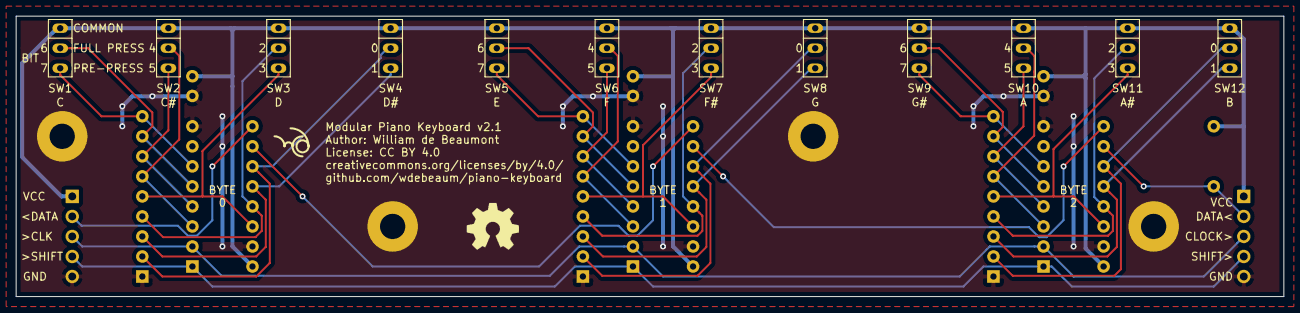
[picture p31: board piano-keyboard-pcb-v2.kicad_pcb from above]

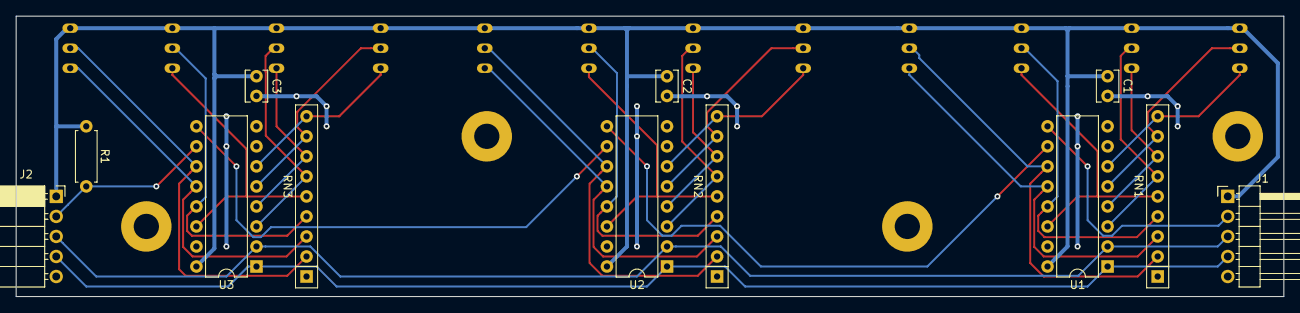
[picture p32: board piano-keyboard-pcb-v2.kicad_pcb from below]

Board: 2 copper layers, 160.8 x 35.6 mm, 24 parts (12 on the bottom side), 32 nets.

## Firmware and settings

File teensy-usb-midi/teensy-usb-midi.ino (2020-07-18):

#include <SPI.h>

#define MAX_OCTAVES 10

// SPI settings for SN74HC165
// Frustratingly, the datasheet gives frequency values at Vcc = 2V, 4.5V, and
// 6V, not 3.3V or 5V. They also depend on temperature. But roughly speaking, a
// lower bound for the maximum clock frequency is about 21MHz at Vcc=3.3V, for
// a wide temperature range. I have been able to run it at 36MHz, but it's not
// really necessary to overclock like that.
// 341,775Hz is the theoretical minimum for scanning a 10-octave keyboard every
// 32 CD audio samples.
// 500KHz is a comfortable margin above that, and seems to work well for 3
// octaves at least.
#define SPI_74165_FREQ 500000
// SN74HC165 datasheet says that data is shifted on the rising edge of the
// clock (so should be read by Teensy on the falling edge), and seems to imply
// that clock is low when inactive. So CPOL=0, CPHA=1, therefore MODE=1. But
// experimentally, CPHA=0/MODE=0 seems to work better? Sometimes?
// ¯\_(ツ)_/¯
#define SPI_74165_MODE SPI_MODE0

// Which pin on the Teensy is connected to the SH/~LD pin on the SN74HC165?
#define SH_LD_PIN 9
// Should we try to do more precise delays around changing the SH/~LD signal
// with a busy-wait loop, or just use delayMicroseconds(1)?
//#define SH_LD_BUSY_WAIT
// if SH_LD_BUSY_WAIT, how many long multiplications should we loop over in
// order to wait enough time (>=~20ns at Vcc=5V) after changing the SH/~LD
// signal?
// Experimentally, doing 6500 long multiplications gives me ~22ns on Teensy 4.0.
#define SH_LD_DELAY_COUNT 6500
// I also tried connecting MOSI to SH/~LD, and sending B11111101 before
// reading, but that had timing issues when >2 octaves were connected.

byte scan_count;
unsigned long switch_states[MAX_OCTAVES];
byte times_since_change[MAX_OCTAVES*24];
byte old_button_states;
byte buf[3];
byte prev_note_num;

// value that can be changed using buttons on end
struct Reg {
  byte value;
  byte small_step;
  byte large_step;
  byte maximum;
};

// indices of registers
#define LOWEST_PITCH_REG 0
#define PROGRAM_REG 1
#define CHANNEL_REG 2
#define NUM_REGS 3

Reg regs[NUM_REGS];
int current_reg;

// usbMIDI library accepts 1-based channel numbers, even though the wire protocol is for 0-based channel numbers
#define CHANNEL (regs[CHANNEL_REG].value + 1)

// potentiometer
struct Pot {
  int pin;
  long old;
  long sum;
  long minimum;
  long center;
  long center_midi;
  long maximum;
};

Pot pitch_bend;
Pot modulation;

void init_pot(Pot& pot, long center_midi, int pin) {
  pot.pin = pin;
  pinMode(pin, INPUT_DISABLE); // disable jumps around logic transition levels
  long val = analogRead(pin);
  // use the initial value as the center value unless it's too far away from
  // the theoretical center value analogRead can return; otherwise use the
  // theoretical value (theoretical range is 0-0x3ff)
  long center = ((abs(val-0x200) > 0x100) ? 0x200 : val);
  pot.old = val;
  pot.sum = 0;
  pot.minimum = (center < val ? center : val);
  pot.center = center;
  pot.center_midi = center_midi;
  pot.maximum = (center > val ? center : val);
}

// return a midi control value corresponding to the read value of the pot
int pot_midi_value(Pot& pot, long val) {
  if (val < pot.center) {
    return (val - pot.minimum) * pot.center_midi / (pot.center - pot.minimum);
  } else {
    return (val - pot.center) * pot.center_midi / (pot.maximum - pot.center) + pot.center_midi;
  }
}

// return new midi value if it changed enough to warrant a message about it;
// otherwise return -1
long update_pot(Pot& pot) {
  long val = analogRead(pot.pin);
  pot.sum += val;
  if (scan_count % 64 == 0) { // 64 scans since last computed value
    val = pot.sum / 64;
    pot.sum = 0;
    long old_midi_val = pot_midi_value(pot, pot.old);
    if (pot.minimum > val) pot.minimum = val;
    if (pot.maximum < val) pot.maximum = val;
    long new_midi_val = pot_midi_value(pot, val);
    if (old_midi_val != new_midi_val) {
      pot.old = val;
      // only start reporting values once we start getting reasonable estimates
      // of min/max values (i.e. far enough from center)
      if (pot.center - pot.minimum > 0x80 && pot.maximum - pot.center > 0x80) {
	return new_midi_val;
      } else { // otherwise, assume user hasn't really moved the pot, and we're just picking up noise
	return -1;
      }
    } else { // value hasn't changed significantly
      return -1;
    }
  } else { // hasn't been long enough since last computed value
    return -1;
  }
}

void setup() {
  pinMode(SH_LD_PIN, OUTPUT);
  SPI.begin();
  SPI.beginTransaction(SPISettings(SPI_74165_FREQ, MSBFIRST, SPI_74165_MODE));
  scan_count = 0;
  memset(switch_states, 0, MAX_OCTAVES*sizeof(long));
  memset(times_since_change, 0, MAX_OCTAVES*24);
  old_button_states = 0;
  regs[LOWEST_PITCH_REG].value = 12*5; // octave #5
  regs[LOWEST_PITCH_REG].small_step = 1; // half-step
  regs[LOWEST_PITCH_REG].large_step = 12; // octave
  regs[LOWEST_PITCH_REG].maximum = 0x7f-12; // just the highest single octave
  prev_note_num = regs[LOWEST_PITCH_REG].value;
  regs[PROGRAM_REG].value = 0; // piano
  regs[PROGRAM_REG].small_step = 1;
  regs[PROGRAM_REG].large_step = 8; // instrument family
  regs[PROGRAM_REG].maximum = 0x7f;
  regs[CHANNEL_REG].value = 0;
  regs[CHANNEL_REG].small_step = 1;
  regs[CHANNEL_REG].large_step = 4; // only 16 channels; 4 is half the bits
  regs[CHANNEL_REG].maximum = 0xf;
  init_pot(pitch_bend, 0x1fff, PIN_A0);
  init_pot(modulation, 0x3f, PIN_A1);
}

void loop() {
  scan_count++;
  unsigned long now = micros();
  // load key state into shift regs
  digitalWrite(SH_LD_PIN, LOW);
#ifdef SH_LD_BUSY_WAIT
  long delay1, delay2=3;
  for (delay1 = 0; delay1 < SH_LD_DELAY_COUNT; delay1++)
    delay2 *= delay1;
#else
  delayMicroseconds(1);
#endif
  digitalWrite(SH_LD_PIN, HIGH);
#ifdef SH_LD_BUSY_WAIT
  for (delay1 = 0; delay1 < SH_LD_DELAY_COUNT; delay1++)
    delay2 *= delay1;
#else
  delayMicroseconds(1);
#endif
  // read state of control buttons on end, and sustain pedal
  byte new_button_states = SPI.transfer(B11111111);
  // which states have changed?
  byte button_changes = new_button_states ^ old_button_states;
  old_button_states = new_button_states;

  // sustain pedal
  if (button_changes & 1) { // sus pedal changed
    if (new_button_states & 1) { // sus pedal pressed
      usbMIDI.sendControlChange(0x40, 0x7f, CHANNEL);
    } else { // sus pedal released
      usbMIDI.sendControlChange(0x40, 0x00, CHANNEL);
    }
  }

  // get just the buttons that just started being pressed
  byte button_presses = button_changes & new_button_states;
  int prev_lowest_pitch = regs[LOWEST_PITCH_REG].value;
  // interpret button presses as changing register values or switching registers
  if (button_presses & (1<<1)) { // fast up
    regs[current_reg].value += regs[current_reg].large_step;
    if (regs[current_reg].value > regs[current_reg].maximum) {
      regs[current_reg].value %= regs[current_reg].large_step;
    }
  }
  if (button_presses & (1<<2)) { // up
    regs[current_reg].value += regs[current_reg].small_step;
    if (regs[current_reg].value > regs[current_reg].maximum) {
      regs[current_reg].value %= regs[current_reg].small_step;
    }
  }
  if (button_presses & (1<<3)) { // left
    if (current_reg == 0) {
      current_reg = NUM_REGS;
    }
    current_reg--;
  }
  if (button_presses & (1<<4)) { // clear
    regs[current_reg].value = 0;
  }
  if (button_presses & (1<<5)) { // fast down
    if (regs[current_reg].value < regs[current_reg].large_step) {
      regs[current_reg].value =
        regs[current_reg].maximum + regs[current_reg].value
	- regs[current_reg].large_step;
    } else {
      regs[current_reg].value -= regs[current_reg].large_step;
    }
  }
  if (button_presses & (1<<6)) { // down
    if (regs[current_reg].value < regs[current_reg].small_step) {
      regs[current_reg].value =
        regs[current_reg].maximum + regs[current_reg].value
	- regs[current_reg].small_step;
    } else {
      regs[current_reg].value -= regs[current_reg].small_step;
    }
  }
  if (button_presses & (1<<7)) { // right
    current_reg++;
    if (current_reg == NUM_REGS) {
      current_reg = 0;
    }
  }
  if (current_reg == PROGRAM_REG && button_presses & B01100110) {
    // program register (instrument) changed
    usbMIDI.sendProgramChange(regs[PROGRAM_REG].value, CHANNEL);
  }

  // if any buttons were just pressed, re-send the last note with the new
  // settings to indicate what changed
  // TODO? somehow indicate current_reg when left/right pressed
  if (button_presses != 0) { // some button was newly pressed
    if (current_reg == LOWEST_PITCH_REG) // changed transposition
      prev_note_num += regs[LOWEST_PITCH_REG].value - prev_lowest_pitch;
    usbMIDI.sendNoteOn(prev_note_num, 0x7f, CHANNEL);
    delay(250);
    usbMIDI.sendNoteOff(prev_note_num, 0, CHANNEL);
  }

  // read key states and send note on/off messages
  for (int o = 0; o < MAX_OCTAVES; o++) {
    buf[0] = SPI.transfer(B11111111);
    buf[1] = SPI.transfer(B11111111);
    buf[2] = SPI.transfer(B11111111);
    // pullup resistor indicates high end of octave chain
    if (buf[0] == B11111111 && buf[1] == B11111111 && buf[2] == B11111111) {
      break;
    }
    unsigned long new_state =
      // force big-endian interpretation so that bits go in a consistent order
      ((unsigned long)buf[0])<<16 |
      ((unsigned long)buf[1])<<8 |
      (unsigned long)buf[2];
    unsigned long old_state = switch_states[o];
    switch_states[o] = new_state;
    unsigned long changes = new_state ^ old_state;
    for (int s = 0; s < 24; s++, new_state >>= 1, changes >>= 1) {
      int tsci = o * 24 + s;
      if (changes & 1) { // switch changed state
	times_since_change[tsci] = 0;
      // otherwise increment time since this switch changed state (clamped)
      } else if (times_since_change[tsci] < 0x80) {
	times_since_change[tsci]++;
	if (times_since_change[tsci] == 1 &&
	    (s&1) == 0 // key-fully-down bits are even, have 0 in the 1s place
	   ) {
	  // key-fully-down switch changed state last scan and stayed there
	  byte note_num = regs[LOWEST_PITCH_REG].value + (o + 1) * 12 - (s>>1) - 1;
	  if (new_state & 1) { // key pressed
	    // get the time since the key-partly-down switch changed and use it
	    // to compute velocity
	    int kpdi = tsci^1; // key-partly-down bits toggle the 1s place
	    byte velocity = 0x80 - times_since_change[kpdi];
	    usbMIDI.sendNoteOn(note_num, velocity, CHANNEL);
	    prev_note_num = note_num;
	  } else { // key released
	    usbMIDI.sendNoteOff(note_num, 0, CHANNEL);
	  }
	}
      }
    }
  }

  // read knob states
  long new_pitch_bend = update_pot(pitch_bend);
  if (new_pitch_bend >= 0) { // changed
    // the library function for this doesn't seem to work right
    //usbMIDI.sendPitchBend((unsigned int)new_pitch_bend, CHANNEL);
    // instead, do it ourselves:
    usbMIDI.send((byte)B11100000, // type
                 (byte)(new_pitch_bend & B01111111), // low 7 bits
                 (byte)((new_pitch_bend >> 7) & B01111111), // high 7 bits
                 CHANNEL, // channel
                 0 // cable (WTF, usbMIDI library?)
                );
  }
  long new_modulation = update_pot(modulation);
  if (new_modulation >= 0) { // changed
    usbMIDI.sendControlChange(0x01, (byte)new_modulation, CHANNEL);
  }

  usbMIDI.send_now(); // flush midi output buffer to usb

  while (usbMIDI.read()) {} // ignore midi input from usb

  // delay until time for next scan, 32CD audio samples (1/44100 second) after
  // start of this scan
  unsigned long later = now + 725; // microseconds
  now = micros();
  if (later > now) {
    delayMicroseconds(later - now);
  }
}

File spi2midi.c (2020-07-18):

// USAGE:
// ./spi2midi >/dev/snd/midiC1D0

#include <stdio.h>
#include <stdlib.h>
#include <stdint.h>
#include <string.h>
#include <time.h>
#include <errno.h>
#include <fcntl.h>
#include <unistd.h>
#include <sys/ioctl.h>
#include <linux/types.h>
#include <linux/spi/spidev.h>
#include "wiring.h"
#include "gpio.h"

int ioctl_or_die(int fd, unsigned long request, void* arg) {
  fprintf(stderr, "ioctl\n");
  int result = ioctl(fd, request, arg);
  if (result == -1) {
    perror("ioctl failed");
    exit(1);
  }
  return result;
}

// 30MHz clock (within spec for SN74HC165N at Vcc=4.5V and 25°C)
#define MAX_SPEED_HZ 30000000
#define MAX_OCTAVES 10

int main(int argc, char** argv) {
  setup_gpio();
  // open the SPI device
  int fd = open(SPIDEV_PATH, O_RDONLY);
  if (fd == -1) {
    perror("failed to open spi device");
    exit(1);
  }
  // set SPI parameters
  char mode = 1; // clock pulses are positive, data read on falling edge
  ioctl_or_die(fd, SPI_IOC_WR_MODE, &mode);
  char bits_per_word = 8;
  ioctl_or_die(fd, SPI_IOC_WR_BITS_PER_WORD, &bits_per_word);
  uint32_t max_speed_hz = MAX_SPEED_HZ;
  ioctl_or_die(fd, SPI_IOC_WR_MAX_SPEED_HZ, &max_speed_hz);

  unsigned char buf[3];
  const int msg_len = 3;
  // the current state of each key switch (two per key, as 24 bits in each
  // octave, from C=(1<<{0,1}) to B=(1<<{22,23}); higher bit comes on first
  // when key is pressed)
  uint32_t switch_states[MAX_OCTAVES];
  memset(switch_states, 0, MAX_OCTAVES*sizeof(uint32_t));
  // the number of scans elapsed since the state of each switch changed
  unsigned char times_since_change[MAX_OCTAVES*24];
  memset(times_since_change, 0, MAX_OCTAVES*24);
  for(;;) {
    // get time at start of scan
    struct timespec now;
    if (clock_gettime(CLOCK_MONOTONIC, &now) == -1) {
      perror("error getting initial time");
      exit(1);
    }
    // parallel-load key states into shift registers
    *clrs = (1<<SH); // send SH/~LD pin low to LoaD
    // delay ~20ns (datasheet says min 14ns @4.5V VCC; each iteration ~1/25ns)
    int iters = 20 * 25;
    for (int i = 0; i < iters; i++)
      ;
    // serial-shift key states from shift registers to raspi, and interpret
    *sets = (1<<SH); // send SH/~LD pin high to SHift
    for (int o = 0; o < MAX_OCTAVES; o++) {
      int bytes_read = read(fd, buf, msg_len);
      if (bytes_read == -1) {
	perror("failed to read from spi device");
	exit(1);
      } else if (bytes_read < msg_len) {
	fprintf(stderr, "short read: %d out of %d bytes\n", bytes_read, msg_len);
      }
      //fprintf(stderr, "buf = %x %x %x\n", (int)buf[0], (int)buf[1], (int)buf[2]);
      // pullup resistor indicates end of octave chain
      if (buf[0] == 0xFF && buf[1] == 0xFF && buf[2] == 0xFF) {
	break;
      }
      uint32_t new_state =
        // force big-endian interpretation so that bits go in a consistent order
        ((uint32_t)buf[0])<<16 |
	((uint32_t)buf[1])<<8 |
	(uint32_t)buf[2];
      uint32_t old_state = switch_states[o];
      switch_states[o] = new_state;
      uint32_t changes = new_state ^ old_state;
      for (int s = 0; s < 24; s++, new_state >>= 1, changes >>= 1) {
	int tsci = o * 24 + s;
	if (changes & 1) { // switch changed state
	  /*fprintf(stderr, "byte %d bit %d in octave %d changed to %d after %d scans (tsci=%d)\n",
	          s>>3, s&7, o, new_state&1, times_since_change[tsci], tsci);*/
	  // reset time since this switch changed state
	  times_since_change[tsci] = 0;
	// otherwise increment time since this switch changed state (clamped)
	} else if (times_since_change[tsci] < 0x80) {
	  times_since_change[tsci]++;
	  if (times_since_change[tsci] == 1 &&
	      (s&1) == 0 // key-fully-down bits are even, have 0 in the 1s place
	     ) {
	    // key-fully-down switch changed state last scan and stayed there
	    unsigned char note_num = (o + 1 +5/*TODO octave selector*/) * 12 - (s>>1) - 1;
	    if (new_state & 1) { // key pressed
	      // get the time since the key-partly-down switch changed and use
	      // it to compute velocity
	      int kpdi = tsci^1; // key-partly-down bits toggle the 1s place
	      unsigned char velocity = 0x80 - times_since_change[kpdi];
	      fprintf(stderr, "key %d in octave %d (bit %d, note %d) pressed with velocity %d\n",
		      s/2, o, s, (int)note_num, (int)velocity);
	      buf[0] = 0x90;
	      buf[1] = note_num;
	      buf[2] = velocity;
	    } else { // key released
	      fprintf(stderr, "key %d in octave %d released\n", s/2, o);
	      buf[0] = 0x80;
	      buf[1] = note_num;
	      buf[2] = 0;
	    }
	    // emit MIDI event
	    int bytes_written = fwrite(buf, 1, 3, stdout);
	    if (bytes_written < 0) {
	      perror("failed to write midi event");
	      exit(1);
	    } else if (bytes_written != 3) {
	      fprintf(stderr, "short write of midi event\n");
	    }
	    if (fflush(stdout) != 0) {
	      perror("failed to flush midi event");
	      exit(1);
	    }
	  }
	}
      }
    }
    // delay until time for next scan, 32 CD audio samples (1/44100 second)
    // after start
    struct timespec later = now;
    unsigned long nsecs = now.tv_nsec + 725623;
    later.tv_sec += nsecs / 1000000000;
    later.tv_nsec = nsecs % 1000000000;
    for(;;) {
      int err = clock_nanosleep(CLOCK_MONOTONIC, TIMER_ABSTIME, &later, NULL);
      if (err == 0) { // success
	break;
      } else if (err == EINTR) { // interrupted, try again
      } else { // some other error
        perror("error while nanosleeping");
	exit(1);
      }
    }
  }
  return 0;
}

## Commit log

2020-03-06 initial version of program to read keyboard via SPI on RasPi and write MIDI events
2020-03-06 actually call setup_gpio() (d'oh!); fix endianness
    [spi2midi.c]
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2020-03-06 git unification
    This version is where I am while merging the different parts of this project into one unified git repo. The PCB is at v2, the version first sent to be manufactured. The 3D model is at a point where it should be compatible with the PCB, and various issues with printing it have been addressed, but not tested. The spi2midi stuff used to be in its own repo; the PCB and 3D model I just kept in a succession of dated/versioned directories. I've done my best to represent the history up to this point in this repo.
    [piano-keyboard-pcb-v2.kicad_pcb, piano-keyboard-pcb-v2.sch, piano-keyboard-pcb.kicad_pcb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]
2020-03-21 update TODO after both printing base and getting pcb made and seeing how they fit
    [piano-keyboard.scad]
2020-03-21 do what I set out to in prev. commit
    [piano-keyboard.scad]
2020-03-22 update TODO after printing another base segment
    [piano-keyboard.scad]
2020-03-26 increase bpin radius more and adjust angle to match; make more notes
    [piano-keyboard.scad]
2020-03-26 swap sense of key bit pairs in spi2midi.c to match new pcb layout
    [spi2midi.c]
2020-03-29 better document how sense of key bits is determined; add debug print
2020-03-29 ughghgh, == binds tighter than &
    [spi2midi.c]
2020-03-30 decide on gluing cardboard to base for stability; print c-f half again
    [piano-keyboard.scad]
2020-04-03 clean up TODO; print C key
    [piano-keyboard.scad]
2020-04-05 try printing two keys, not diagonal, to mitigate curl in both directions
    [piano-keyboard.scad]
2020-04-07 fix MIDI note number calculation
    [spi2midi.c]
2020-04-19 print high half of base
    [piano-keyboard.scad]
2020-04-21 print F and G keys
    [piano-keyboard.scad]
2020-04-25 print last two white keys, A and B
    [piano-keyboard.scad]
2020-05-03 print 3 black keys
    [piano-keyboard.scad]
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2020-05-07 improve PCB support:
    - switch from pegs to holes for M3 screws
    - cut out a bit of A# key to accommodate screw head
    - make trenches under PCB supports smaller so support is stiffer
    also: explain parameters better in comments
    [piano-keyboard.scad]
2020-05-08 refactor and document more, and add more ghost parts in assembled version; replace "fit tests" with series of recommended prints
    [piano-keyboard.scad]
2020-05-17 decrease screw hole radius so that threads bite more
    [piano-keyboard.scad]
2020-05-17 bridge over peak of teardrop-shaped skewer holes to avoid curling up into bobby pin slots
    [piano-keyboard.scad]
2020-05-21 echo cardboard dimensions
    [piano-keyboard.scad]
2020-05-21 add option to print black keys in two prints per octave to avoid curling
    [piano-keyboard.scad]
2020-05-21 add README.md, and a rule for making README.html from it
    [piano-keyboard.scad]
2020-06-06 schematic for PCB at the end, to connect to Teensy 4.0
    [piano-keyboard-end-pcb.kicad_pcb, piano-keyboard-end-pcb.sch]
2020-06-07 start laying out end pcb
    [piano-keyboard-end-pcb.kicad_pcb, piano-keyboard-end-pcb.sch]
2020-06-07 finish adding footprints, including custom one for 1/4" mono jack; do rough part layout
    [piano-keyboard-end-pcb.kicad_pcb, piano-keyboard-end-pcb.sch]
2020-06-07 put most parts on front side, align to 50mil grid
    [piano-keyboard-end-pcb.kicad_pcb]
2020-06-07 add traces and silkscreen labels; rearrange buttons to make traces easier
    [piano-keyboard-end-pcb.kicad_pcb]
2020-06-07 make a simple 3d model for the 1/4" mono jack
    [piano-keyboard-end-pcb.kicad_pcb]
2020-06-07 make a simple 3d model for the pots (KiCAD doesn't actually have this)
    [piano-keyboard-end-pcb.kicad_pcb]
2020-06-07 move mod pot right so it aligns with edge and pitch bend pot
    [piano-keyboard-end-pcb.kicad_pcb]
2020-06-07 move pitch bend pot up slightly to align with 10mil grid
    [piano-keyboard-end-pcb.kicad_pcb]
2020-06-07 rough sketch of end enclosure to make sure I have all the features in the right places
    [piano-keyboard-end.scad]
2020-06-08 correct button dimensions
    [piano-keyboard-end.scad]
2020-06-09 fix potentiometer shaft radius, and add its length to scad params
    [piano-keyboard-end.scad]
2020-06-09 add knobs
    [piano-keyboard-end.scad]
2020-06-09 make a big TODO comment about how to finish the end enclosure
    [piano-keyboard-end.scad]
2020-06-09 rename piano-keyboard=>octave and piano-keyboard-end=>end
    [end.scad, octave.scad, piano-keyboard-end-pcb.kicad_pcb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]
2020-06-09 factor out common.scad from octave.scad and end.scad
    [common.scad, end.scad, octave.scad]
2020-06-09 add anchor point on knob for pitch bend centering torsion spring
    [end.scad]
2020-06-10 make assemblable by extending sus/usb port holes and removing bottom wall; add pcb shelves; taper top around teensy
    [common.scad, end.scad, octave.scad]
2020-06-10 much work on enclosure:
    - add skewer
    - make button extension pieces
    - separate button panel from rest of enclosure
    - add separate assembled and plated_* modules
    [end.scad]
2020-06-10 shape button holes to match button shaft shapes
    [end.scad]
2020-06-10 add torsion spring anchor hole in enclosure
    [end.scad]
2020-06-10 remove done TODO comment
    [end.scad]
2020-06-11 add my logo to the top of the end enclosure
    [end.scad, logo.scad]
2020-06-11 add cardboard to bottom of assembled end
    [common.scad, end.scad, octave.scad]
2020-06-11 rename things named the same in octave and end; add full assembly in assembled.scad; fix an alignment issue that revealed
    [assembled.scad, end.scad, octave.scad]
2020-06-11 start writing code for teensy (collect all the library calls I'll need)
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2020-06-14 set analog input pins' mode to INPUT_DISABLE
    This disables the digital input circuitry on those pins, which was
    causing discontinuities in the analog values around where the digital
    value would switch.
2020-06-14 return -1 from update_pot() when scan_count!=0
    (WTF, how did the compiler not catch the missing return statement?)
    [teensy-usb-midi.ino]
2020-06-15 try using pin 9 instead of MOSI for SH/~LD in order to have better control over its timing; decrease clock from 30MHz to 26MHz, experimentally the highest I can go with this pin arrangement and 3 oct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
2020-06-15 avoid weird usbMIDI.sendPitchBend() behavior by sending the raw MIDI message myself; make sure I send the 1-based channel number to the usbMIDI library (instead of 0-based)
    [teensy-usb-midi.ino]
2020-06-15 make end PCB use Teensy pin 9 instead of MOSI, to match the software
    Also move the Teensy down to make room for the new connection, and
    reroute traces and rearrange silkscreen to compensate. Also add the
    github URL where this repo will be to the silkscreen.
    [piano-keyboard-end-pcb.kicad_pcb, piano-keyboard-end-pcb.sch]
2020-06-15 adjust Teensy position to match end PCB; also adjust logo position
    [end.scad]
2020-06-15 bevel edges of knobs
    [end.scad]
2020-06-15 use support_gap instead of gap between end and octave, so that connectors don't overlap too much
    [assembled.scad]
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2020-06-15 replace 1ms delays with ~22ns busy-waits
    [teensy-usb-midi.ino]
2020-06-16 fixes for issues discovered in first print of enclosure:
    - increase width of shelf for button panel (and add left side) so it doesn't fall through
    - increase base radius of screw posts (make them cones) to make them not tip during printing (or ever)
    - increase button panel radius and add cutout in shelf to accommodate bigger front screw post
    - add bottom wall (floor?) on left side to stiffen enclosure and not let button panel push it apart and slip through (but avoid covering screws with this wall)
    - make torsion spring anchor holes bigger to accommodate insulation on wire (AWG rating doesn't include insulation)
    Also add exploded_end() module to better show how to assemble.
    [common.scad, end.scad]
2020-06-16 animate exploded_end()
    [end.scad]
2020-06-16 fix z offset of plated buttons
    [end.scad]
2020-06-17 fixes after printing knobs and buttons:
    - make buttons heads thicker and wider so they actually print the right shape
    - make retention nubs at ends of button shafts bigger so they actually print
    - increase gaps so things actually fit
    [end.scad]
2020-06-18 decrease gap between knob ir and pot shaft slightly; print knobs and button panel to test
    [end.scad]
2020-06-18 more tweaks:
    - make gap between knob and pot shaft slightly smaller still (knob still slipped off too easily)
    - make button shafts slightly longer (concerned they might not hit the buttons)
    - divide triangle button shaft retention nub radius by sqrt(2) so it's not too big (didn't fit in hole)
    - add ghosts showing actual button heights since the model kicad used is too short
    - don't use small_v_hole_shrinkage in z dimension when making button holes
    - make button shaft guides shorter so that ends of button shafts stick out the bottom, and the guides won't accidentally push the buttons
    - make button shaft guides wider so there aren't gaps printed where the triangles poke into the sides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
    [end.scad]
2020-06-27 fixes after printing controls again, and receiving end pcb:
    - increase width of button shafts, narrowing gap
    - increase length of button shafts, so they can reach buttons consistently
    - increase gap on ±Y sides of pcb (including teensy) to account for vertical printing of those slots
    [end.scad]
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2020-06-28 fix end cardboard height
    [end.scad]
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2020-06-28 increase thickness of rectangle button shaft too (oops)
    [end.scad]
2020-06-28 add github link to octave pcb silkscreen; adjust placement of "J2" silkscreen so it doesn't get cut off
    [piano-keyboard-pcb-v2.kicad_pcb]
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2020-06-29 reorder end assembly steps so knobs come after screws, so the enclosure can lay flat on its top while you drive the screws
    [end.scad]
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2020-07-01 improve initial behavior of pots:
    - disable pots until we see raw values far to either side of center, to
    exclude noise before pots are calibrated
    - don't use initial value as center if it's way to one side or the
    other; instead use theoretical center
    [teensy-usb-midi.ino]
2020-07-02 fix control button behavior:
    - fix maximum values (0x7f, not 0x3f, d'oh!)
    - mod by step size instead of subtracting maximum+1, so e.g.
    transposition preserves octave when wrapping
    - register values are unsigned, so avoid testing if they're <0
    [teensy-usb-midi.ino]
2020-07-03 more build instructions tweaks:
    - include measurements for non-printed mechanical parts of end
    - suggest wrapping tape around pot shafts
    - fix old references to "assembled();"
    [end.scad]
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2020-07-04 add picture of end parts to BOM; fix labels in picture of octave parts
2020-07-04 fix swapped gender of octave connectors in BOM
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2020-07-04 fix range of modulation wheel values
    [teensy-usb-midi.ino]
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2020-07-18 use 3.3V throughout, instead of mixing it with 5V levels
    This fixes the issues with the highest few keys intermittently not
    working. It also makes the end PCB a little simpler. The shift registers
    won't run as fast, but it turns out they don't need to.
    [piano-keyboard-end-pcb.kicad_pcb, piano-keyboard-end-pcb.sch]

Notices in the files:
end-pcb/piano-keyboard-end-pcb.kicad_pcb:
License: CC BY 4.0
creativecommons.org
